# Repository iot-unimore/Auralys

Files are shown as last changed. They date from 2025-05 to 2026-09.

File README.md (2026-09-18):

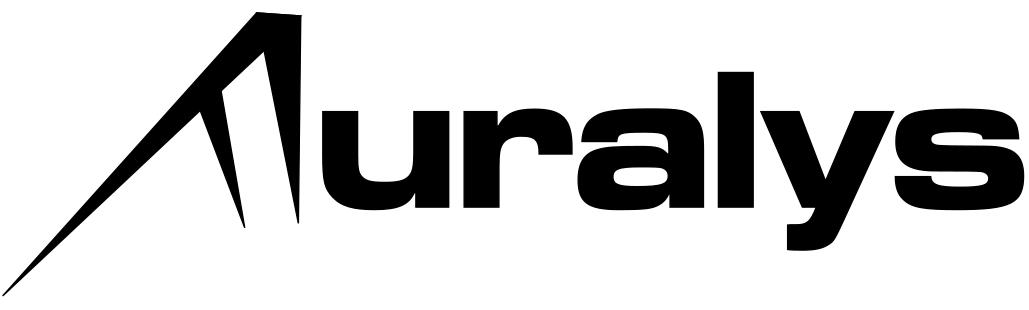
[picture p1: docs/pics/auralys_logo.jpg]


Auralys = Auris + Analysis

Auralys is an automated system for the measurement of head related transfer functions (HRTF) and room impulse
responses (RIR) of wearable devices carrying an array of microphones. It was built to characterise a pair of
glasses with six MEMS microphones, mounted on a 3D printed head, but the measurement system does not depend on
the device: any object with any number of microphones can be placed at the centre of the rig.

The whole system is designed to be rebuilt from this repository: 3D printed parts, off-the-shelf components,
electronics, firmware and software are all here, and no proprietary hardware or software is required.

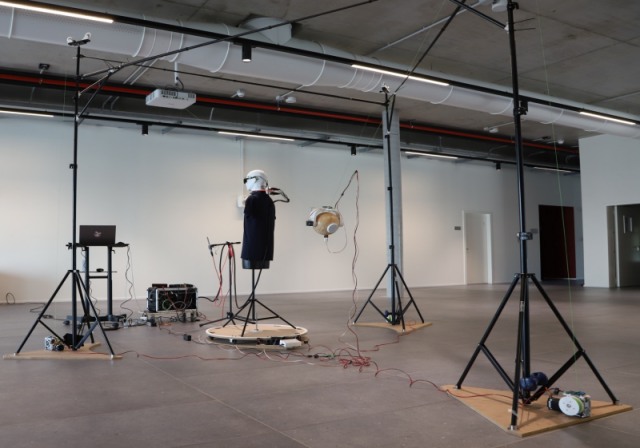
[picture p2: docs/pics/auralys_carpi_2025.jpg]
Auralys_carpi_2025


## What it does

A measurement campaign presents a loudspeaker at every direction of a grid around the device under test, plays an
exponential sine sweep at each direction, and records all the microphones together with a copy of the stimulus on
a single multichannel audio interface, so that all the tracks share one clock. The recordings are then processed
offline into impulse responses and assembled into AES69-2022 (SOFA) files.

The loudspeaker is moved in three dimensions by a cable suspension: three poles, each with a stepper motor winding
a thin rope, hold the speaker at any point of the working volume, and a small gimbal keeps it pointed at the
device. The device itself sits on a turntable that provides the azimuth rotation. Every motor is driven by the
same controller board and the same firmware (`firmware/auralysSpeaker`), configured for its role, and the host
talks to all of them over WiFi through a small REST API.

The work is split in two steps that never run together:

1. **Capture**, driven by `auralysCaptureHRTF.py`: positions the speaker, rotates the table, plays and records the
   sweep, and leaves on disk one folder per direction with the recording and a complete description of the setup
   (`config.yaml`).
2. **Processing**, done by the scripts under `hrtf/compute_hrir.py` and `hrft/compute_3dti_sofa.py`: deconvolution, time of arrival detection, and SOFA
   generation. This step reads only what the capture wrote and can be repeated at any time on any machine.

## Repository layout

| folder | content |
| --- | --- |
| `hardware/` | 3D models, schematics and gerber files: speaker, gimbal, turntable, poles and pulleys, motor controller, MEMS microphone board, power splitter, printed head (OpenAural) |
| `firmware/auralysSpeaker/` | Arduino sketch for the ESP32-S3 motor controller (pole, speaker gimbal, turntable), plus `cli/auralys_ctrl.py`, the command line tool that converts a position into rope lengths and drives the units |
| `hrtf/` | sweep recording (`record_ess_map.py`, `record_ess.py`), impulse response and SOFA computation (`compute_hrir.py`, `compute_3dti_sofa.py`, `compute_sofa.py`), tools; `ess_params.yaml` and `ess_map_params.yaml` describe the setup and the campaign |
| `audio/` | recording of ordinary audio material (not sweeps) over the same positioning loop |
| `docs/` | notes and coordinate tables |
| `auralysCaptureHRTF.py` | top level script for a full HRTF map (this file) |
| `auralysCaptureAudio.py` | top level script for an audio map with the same positioning loop |

Detailed documentation of the individual scripts will be added under `docs/`.

## Requirements

Hardware: the rig as described in `hardware/`, three pole units, one speaker unit and one turntable unit flashed
with the firmware and reachable on the local network, and one audio interface capable of simultaneous playback
and multichannel recording at 96 kHz, 24 bit (the scripts were developed with an RME Fireface UFX and a Focusrite
Scarlett 18i20).

Software: Linux with ALSA (`aplay` is used to find the interface), Python 3 with `numpy`, `pyyaml`, `sounddevice`,
`soundfile`, `requests`, `wget` and `multiprocess` for the capture step; the processing step additionally needs
`scipy`, `pyfar`, `sofar`, `matplotlib` and `setproctitle` (see `hrtf/readme.txt`).

## Running a capture with auralysCaptureHRTF.py

The script has no command line options: everything it needs is a constant at the top of the file, above the line
`DO NOT MODIFY CODE BELOW THIS LINE`. Before the first run:

1. Configure the positioning tool. The IP addresses of the five units, the geometry of the poles (heights and
   distances from the turntable) and the rope calibration constants are at the top of
   `firmware/auralysSpeaker/cli/auralys_ctrl.py`. Check them with a manual move:

   ```
   ./firmware/auralysSpeaker/cli/auralys_ctrl.py -c set position -p 1000,0,1650 -rs 0 -t ac -v
   ./firmware/auralysSpeaker/cli/auralys_ctrl.py -c cmd gozero -rs 0 -rt 0 -v
   ```

2. Describe the setup in `hrtf/ess_params.yaml`: the receivers (name, description, track index on the audio
   interface, position in the listener frame), the emitter (the speaker and the track of its loopback), the room,
   the author and the licence. This file is copied into every measurement as `config.yaml` and everything the
   processing knows about the setup comes from it.

3. Set the sweep parameters and the azimuth grid in `hrtf/ess_map_params.yaml`, or accept the defaults (20 Hz to
   20 kHz, 15 s, amplitude 0.8, 2 s of silence before and after, 96 kHz, 24 bit).

4. Edit the constants of `auralysCaptureHRTF.py`:
   - `_AUDIO_RECORDING_DEVICE_ID` / `_AUDIO_PLAYBACK_DEVICE_ID`: the name of the interface as printed by
     `aplay -l`; both must be the same interface;
   - `_AZIMUTH_BEGIN`, `_AZIMUTH_END`, `_AZIMUTH_STEP`: the azimuth range of every ring (default 360 down to 5 in
     steps of -5, that is 72 directions);
   - `auralysPositions`: one row per elevation ring, `[elevation, x, z]` in degrees and millimetres, with the
     speaker on a circle of 1 m radius around the head origin. Comment out the rows you do not need;
   - the output folder and the session name in the `record_ess_map.py` call (`-m` and `-n`).

Then, with the rig at its home position and the device under test on the table:

```
./auralysCaptureHRTF.py
```

For each ring the script moves the speaker, tilts it towards the head, waits for the ropes to settle, and starts
`hrtf/record_ess_map.py`, which rotates the table to every azimuth and records one sweep per direction. At the end
the speaker and the table are sent back to zero. An elevation the speaker could not reach, or a direction that
could not be recorded, is skipped and listed at the end, and the exit code is non-zero: a run that ends without
errors is complete.

The output is one folder per direction under the session folder:

```
<session>/
  <name>_+000+030+001_xAngle/      azimuth 0, elevation +30, distance 1 m
    config.yaml                    setup and stimulus actually used
    sweep_0.wav                    all interface inputs, 24 bit, 96 kHz
    sweep_99.wav                   preamble recording, not used
  <name>_+355+030+001_xAngle/
  ...
```

A dry run of the mechanics without audio is possible by adding `-t` to the `record_ess_map.py` call in the
script.

## Processing the recordings

The scripts under `hrtf/` turn a session folder into impulse responses and SOFA files; `hrtf/runme_all.sh` runs
the complete sequence on one session and `hrtf/usage_notes.txt` shows the individual commands. The resulting SOFA
files are the input of the [VERSE](https://github.com/iot-unimore/verse) framework.

## Note on the output location: `-m` and `-n`

The two values that change at every campaign are the output folder and the session name, the `-m` and `-n`
options of `hrtf/record_ess_map.py`. They are passed by `auralysCaptureHRTF.py` in its call to
`record_ess_map.py` and are the first thing to edit before a run:

```
"-m", "/media/gfilippi/audiodata/auralysNoHead_20260905-001",   # output folder of the session
"-n", "auralysNoHead",                                          # session name, prefix of every direction folder
```

`-m` is the session folder, created if it does not exist; a full map is several gigabytes of 24 bit
multichannel audio, so point it to a drive with room. Its last path component becomes the prefix of the SOFA
files produced later (`auralysNoHead_20260905-001_binaural.sofa` and so on). `-n` is the prefix of the folder of
every direction (`<name>_+AAA+EEE+DDD_xAngle`) and of the `config.yaml` entries that name it.
Running twice with the same `-m` and `-n` overwrites the recordings of the directions in common, so use a new
session folder for every campaign.

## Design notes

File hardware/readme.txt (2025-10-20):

this folders contains the list of parts to rebuild the speaker, rotating table, suspension poles.

the motor controller is universal (one pcb for all roles, spearker or suspension pole)

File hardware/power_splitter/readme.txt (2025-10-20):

a simple pcb to split the 24v between all the motor controls and rotating table of verse.

diode is present to prevent polarity inversion.

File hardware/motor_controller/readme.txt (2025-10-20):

the motor controller will run the auralysSpeaker firmware and it is the same for ALL the motors in the system.

different settings for speed (and role) allows the software to change the behavior, but the firmware is the same on all devices.

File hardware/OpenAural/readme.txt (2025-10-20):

https://www.thingiverse.com/thing:4691843

https://www.sciencedirect.com/science/article/pii/S0003682X20307143

===

Using both ears the human brain processes both monaural and inter-aural cues resulting from the scattering of sound by the head and torso in order to localise the source of a sound.  A common method to replicate these cues for playback has been to build a human dummy head and torso simulator (HATS) and place microphones at each ear canal to replicate the effect the human anatomy has on the sound field.

A binaural device was successfully designed for manufacture on a range of 3D printers. Full details of the design and experimental validation can be found here:

O’Connor D, Kennedy J. An evaluation of 3D printing for the manufacture of a binaural recording device. Applied Acoustics. 2021 Jan 1;171:107610. 

https://doi.org/10.1016/j.apacoust.2020.107610

The excellent agreement between the developed system and the BEM simulations demonstrates the validity of the system for many acoustic problems. At present the developed system is being used for subjective listening tests in the context of environmental noise annoyance.

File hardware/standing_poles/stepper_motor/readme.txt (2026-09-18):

motor is a MKS SERVO57D (485)

https://makerbase3d.com/product/makerbase-mks-servo57d/

gearbox for rpm reduction

https://it.aliexpress.com/item/1005002212151972.html

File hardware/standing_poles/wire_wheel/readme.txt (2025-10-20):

each wire is suspended over two wheels.

each wheel is made of two parts (identical) glue toghether and attached to the support using two ball bearings.

each plate mounted on top of the pole has two supports for two wheels

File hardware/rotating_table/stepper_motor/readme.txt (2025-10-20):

https://makerbase3d.com/product/makerbase-mks-servo57d/

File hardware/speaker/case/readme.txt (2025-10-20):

the speaker case is made of two bambu bowls glued toghether.

it is a cheap solution to get a rounded shape speaker that can rotate on the horizontal axis

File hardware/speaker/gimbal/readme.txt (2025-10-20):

the gimbal support for the speaker is printed in multiple parts.

- one plate
- two sides
- two curves

that need to be assembled using 4mm and 5mm nuts and bolts

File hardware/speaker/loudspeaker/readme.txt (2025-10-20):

FAITAL-PRO

4FE43 - 8ohm

https://faitalpro.com/en/products/LF_Loudspeakers/product_details/index.php?id=401005100

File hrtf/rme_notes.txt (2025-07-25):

IMPORTANT: 
==========
If you are using an RME (www.rme-audio.de) audio card with linux,
you need to add the following define to ~/.bashrc :

PA_ALSA_PLUGHW=1
export PA_ALSA_PLUGHW

note: make sure to log-out, log-in after adding the above.

FFPLAY specific device playback:
================================
SDL_AUDIODRIVER="alsa" AUDIODEV="hw:2,0" ffplay ./pinknoise_0.8A_30s.wav

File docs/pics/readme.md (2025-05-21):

===

Auralys is the combination of AURIS (meaning ear in latin language) and ANALYSIS

===

The first letter "A" of the Auralys logo is the rune symbol for A, referring to ANSUZ.

The Ansuz rune is associated with divine communication, wisdom, inspiration, and the power of words. 
It signifies the arrival of profound messages and the ability to articulate them clearly, 
whether through spoken words, written texts, or intuitive understanding. 
It also represents the connection between the divine and human, and the reception and application 
of spiritual knowledge. 

Ansuz is often seen as the rune of divine messages and the ability to receive and transmit spiritual knowledge. 

-EOF-

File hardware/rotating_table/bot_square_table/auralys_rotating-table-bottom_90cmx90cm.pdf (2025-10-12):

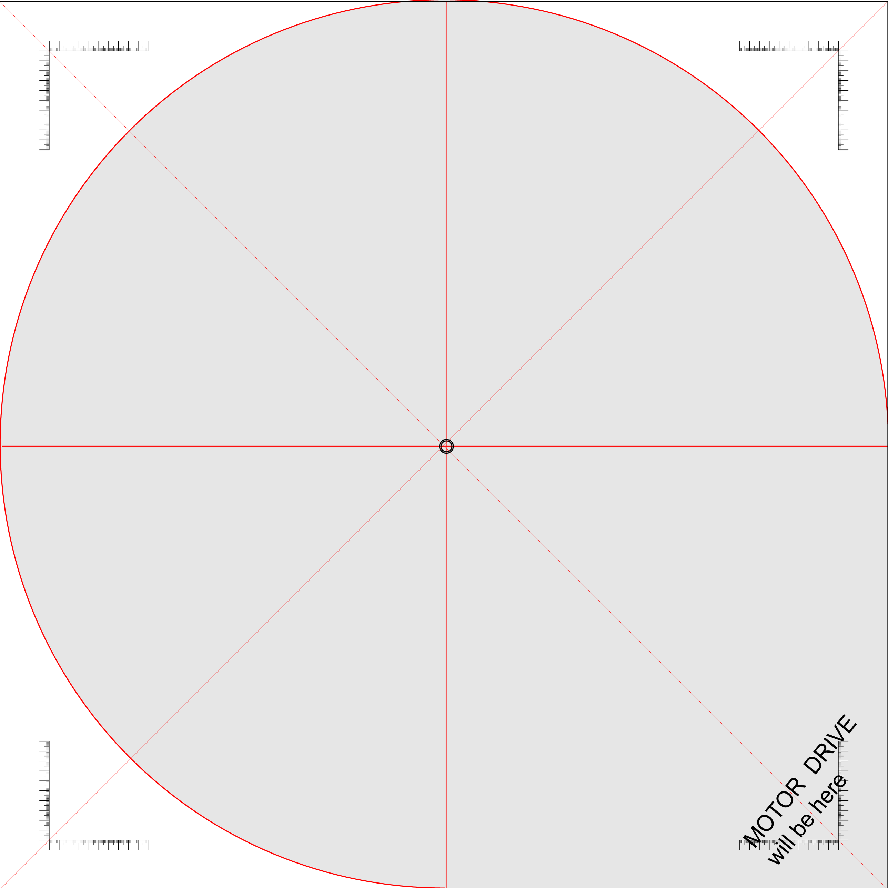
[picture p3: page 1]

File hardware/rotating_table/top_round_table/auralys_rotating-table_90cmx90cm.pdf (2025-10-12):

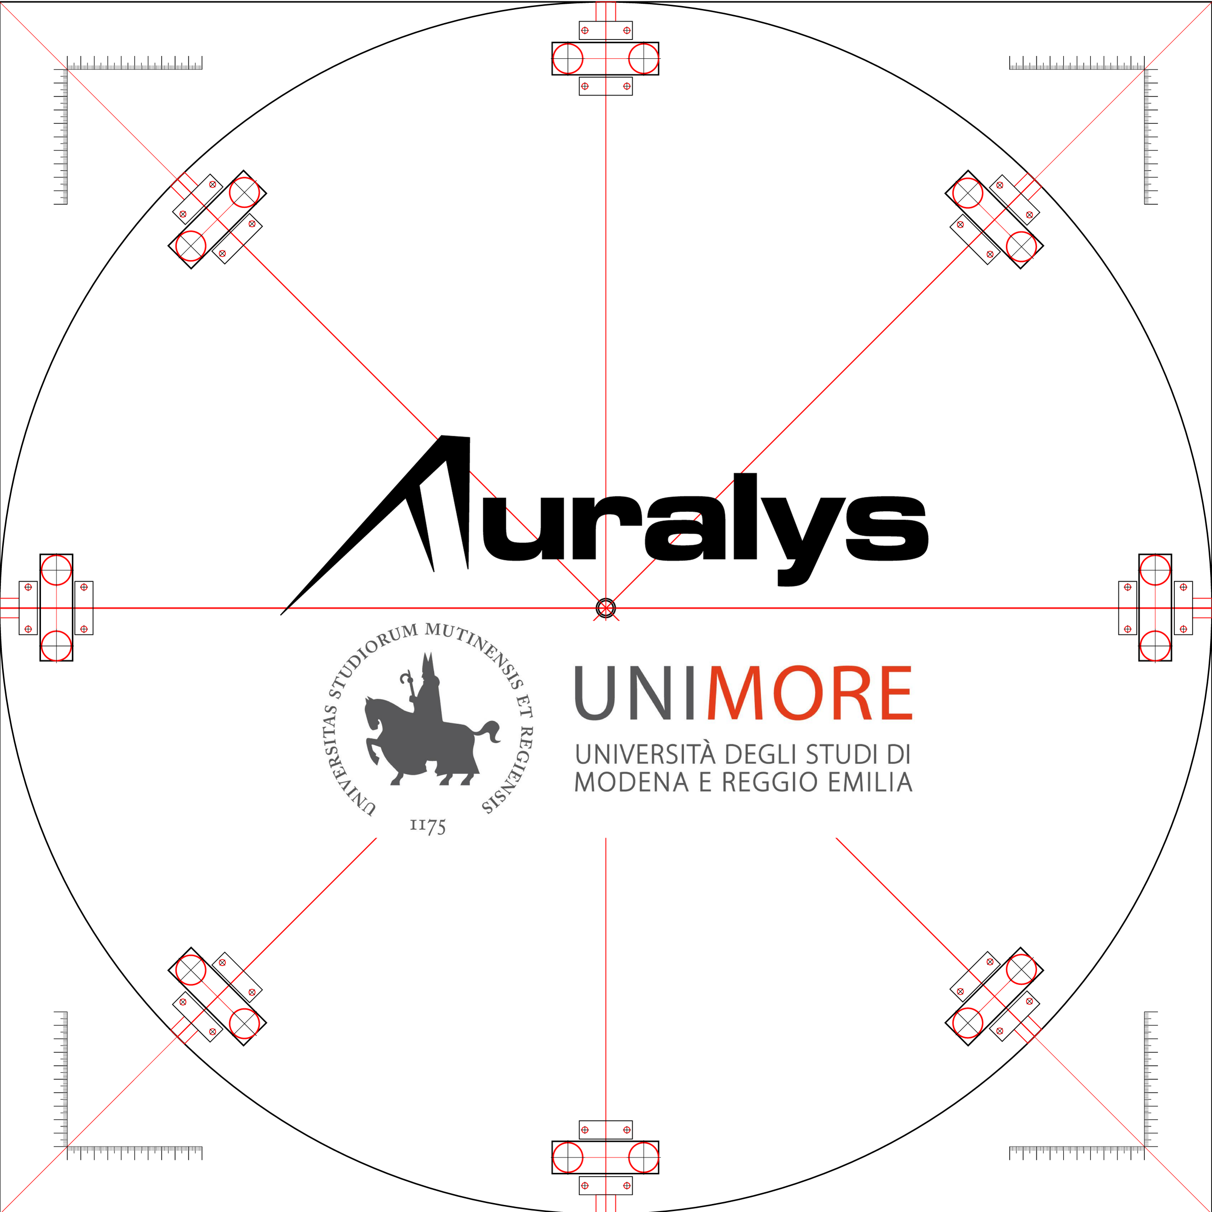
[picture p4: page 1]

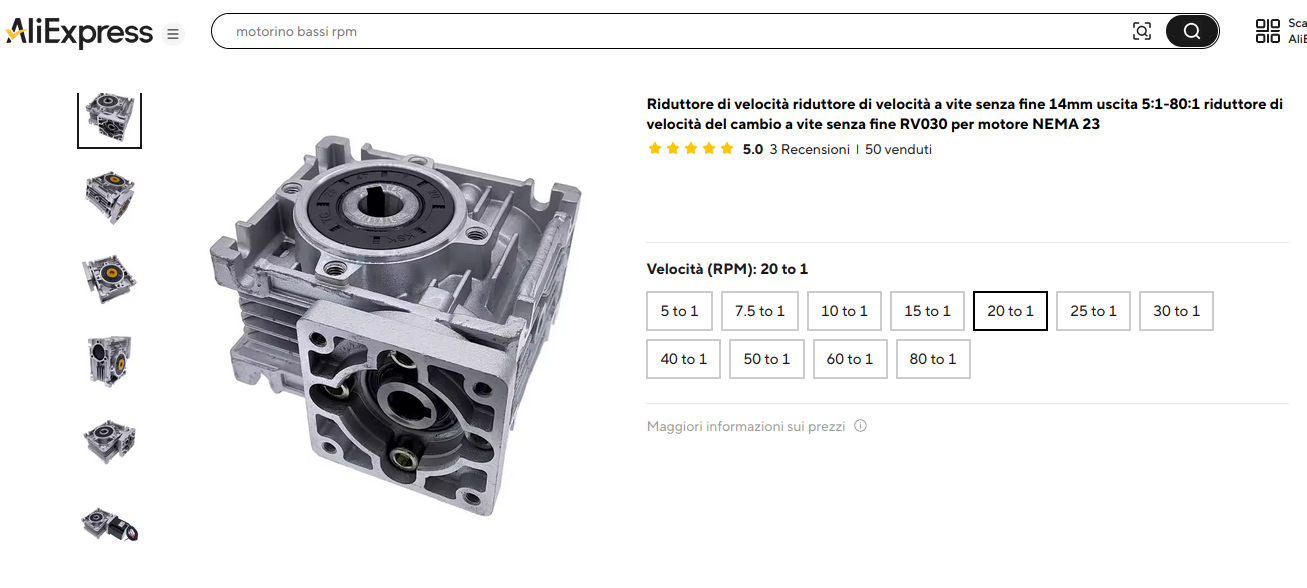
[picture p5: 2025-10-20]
hardware/standing_poles/stepper_motor/gearbox.png

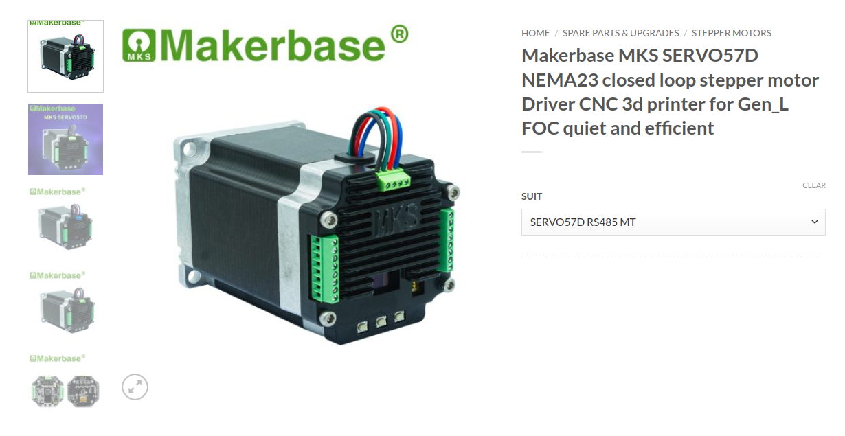
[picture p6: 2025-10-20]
hardware/rotating_table/stepper_motor/mks_servo57D_485.png

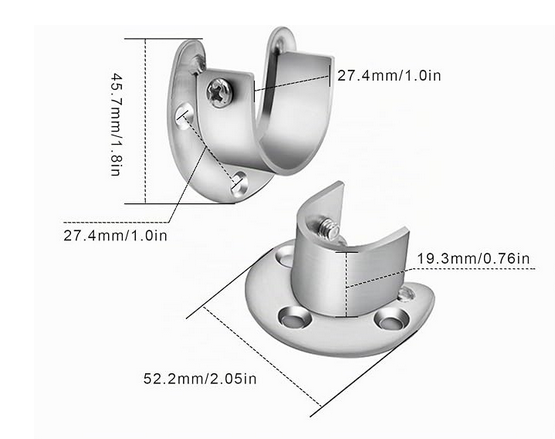
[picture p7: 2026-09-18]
hardware/standing_poles/feed_asapters.png

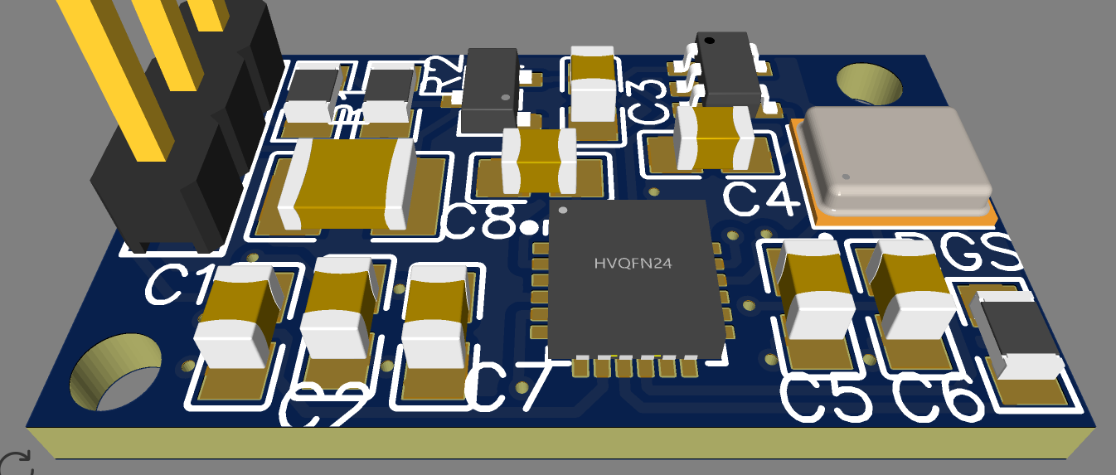
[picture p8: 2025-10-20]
hardware/glasses/mems_mic/mems_mic.png

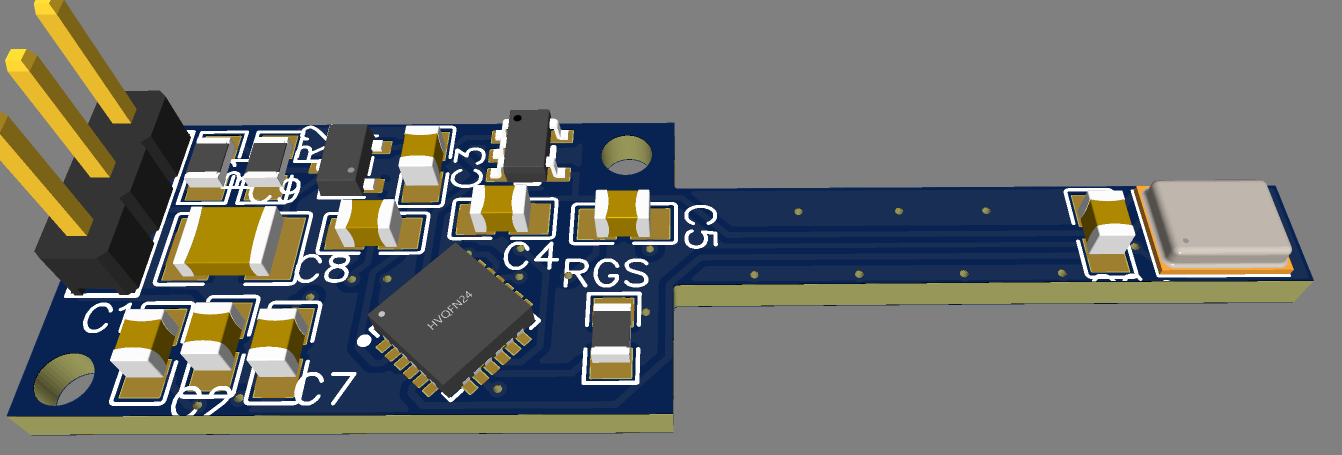
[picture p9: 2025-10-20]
hardware/glasses/mems_mic/mems_mic_long.png

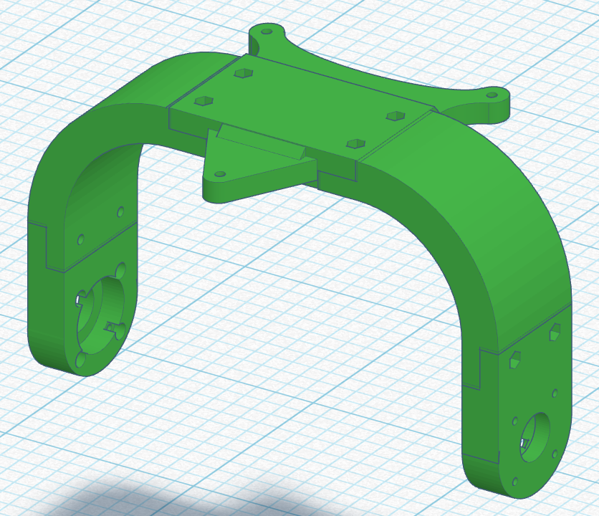
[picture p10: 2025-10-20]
hardware/speaker/gimbal/auralys_speaker_gimbal_01.png

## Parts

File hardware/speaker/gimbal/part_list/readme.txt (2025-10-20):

the gimbal stepper motor is controlled by a MAKERBASE MKS 42S (RS485) controller

https://makerbase.com.cn/en/

https://makerbase3d.com/product-category/brands/mks/servo/

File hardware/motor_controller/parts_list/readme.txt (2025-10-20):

MAIN CPU:
https://www.wemos.cc/en/latest/s3/s3_mini.html

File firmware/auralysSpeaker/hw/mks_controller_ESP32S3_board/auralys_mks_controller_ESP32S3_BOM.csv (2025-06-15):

ID | Name | Designator | Footprint | Quantity | Manufacturer Part | Manufacturer | Supplier | Supplier Part | Price
1 | HDR-F-2.54_1x3 | H4 | HDR-F-2.54_1X3 | 1 |  |  | LCSC | C146690 | 0.086
2 | AO3400A_C347475 | Q1 | SOT-23-3_L2.9-W1.3-P1.90-LS2.4-BR | 1 | AO3400A | UMW(友台半导体) | LCSC | C347475 | 0.031
3 | WEMOS-S3-MINI | U1 | WEMOS-S3-MINI | 1 | Wemos | WEMOS | WEMOS | WEMOS_S3_MINI
4 | 10kΩ | R1,R2,R3,R4,R5 | R0805 | 5 | 0805W8F1002T5E | UNI-ROYAL(厚声) | LCSC | C17414 | 0.002
5 | HDR-F-2.54_1x2 | H1,H3 | HDR-F-2.54_1X2 | 2 |  |  | LCSC | C49661 | 0.038
6 | ADJ-STEP-DOWN | U4 | ADJ-STEP-DW | 1
7 | SERIAL-to-485 | U5 | SERIAL-TO-485 | 1
8 | PWR_YE0192 | U6 | PWR_YE1092 | 1
9 | JST-XH-04-PIN-LONG-PAD | X1 | JST-XH-04-PACKAGE-LONG-PAD | 1
10 | K2-3.6×6.1_SMD | KEY1,KEY2,KEY3 | KEY-SMD_2P-L6.2-W3.6-LS8.0 | 3 | K2-1107ST-A4SW-06 |  | LCSC | C118141 | 0.062
11 | WCMCU-LIS3DH | U2 | WCMCU_LIS3DH | 1
12 | GME12864 | U3 | OLED-GME12864 | 1 | 1.3寸OLED显示屏12864 | null |  | C9900014198

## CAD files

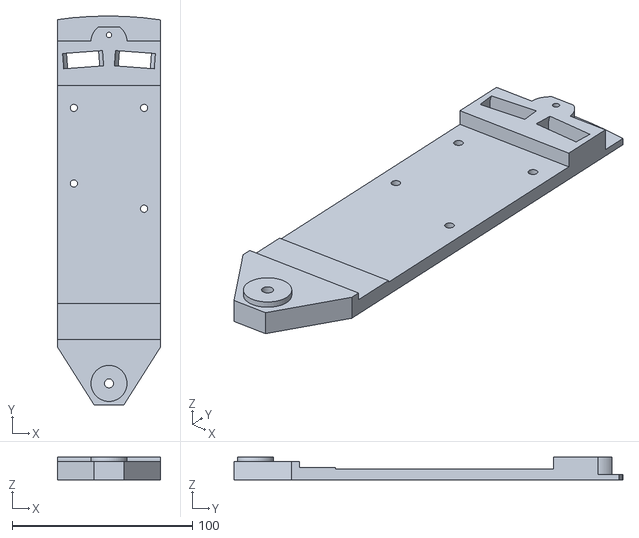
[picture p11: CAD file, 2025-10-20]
hardware/rotating_table/stepper_motor/motor_support/MKS_RTable_FULL.stl
57.0 x 216.0 x 12.5

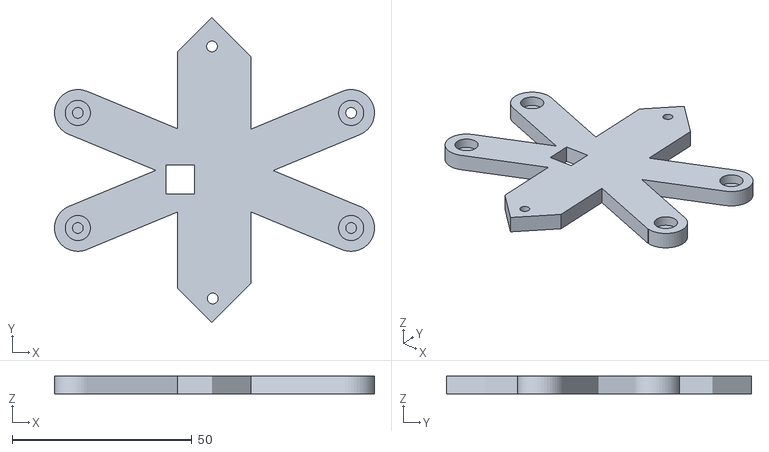
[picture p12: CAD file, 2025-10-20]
hardware/motor_controller/MKS_ctrl_star_mount.stl
89.0 x 84.9 x 5.00

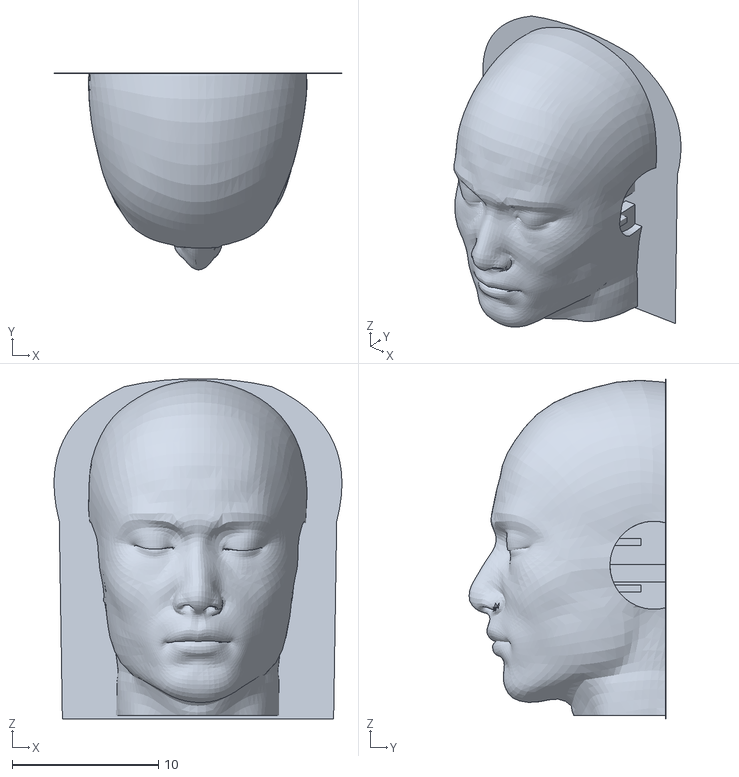
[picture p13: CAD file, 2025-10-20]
hardware/OpenAural/Head_front.STL
19.7 x 13.5 x 23.3

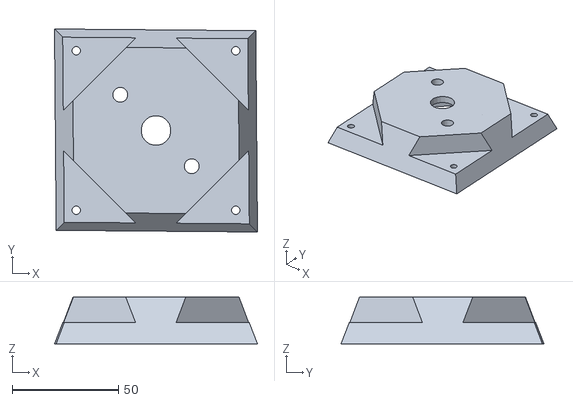
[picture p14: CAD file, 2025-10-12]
hardware/rotating_table/bot_square_table/parts_list/center_shaft_bearing_support.stl
95.5 x 95.5 x 22.0

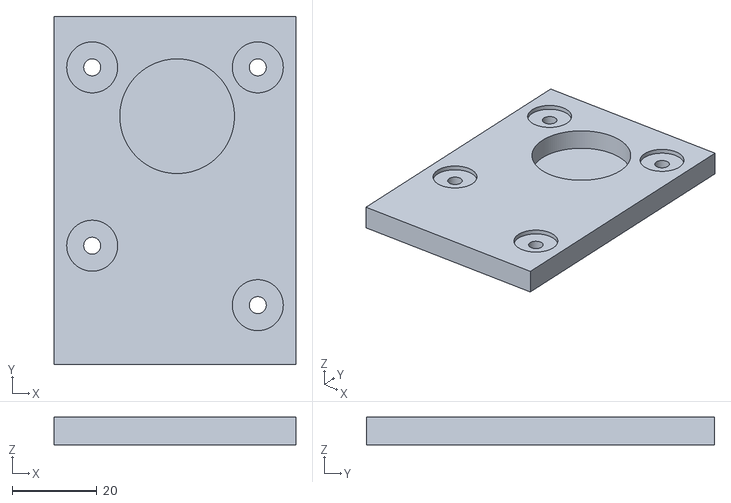
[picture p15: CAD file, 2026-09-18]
hardware/rotating_table/stepper_motor/motor_support/MKS_RTable_gearbox_plate.stl
57.0 x 82.0 x 6.50

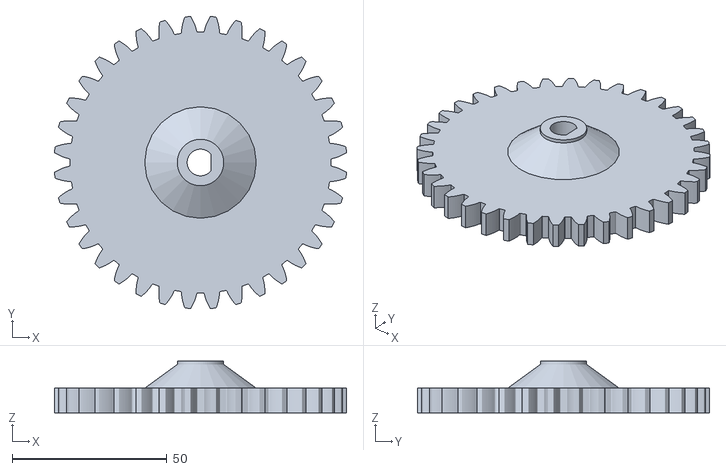
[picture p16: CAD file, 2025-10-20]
hardware/rotating_table/stepper_motor/spurgear-III_small.stl
94.3 x 94.3 x 16.8

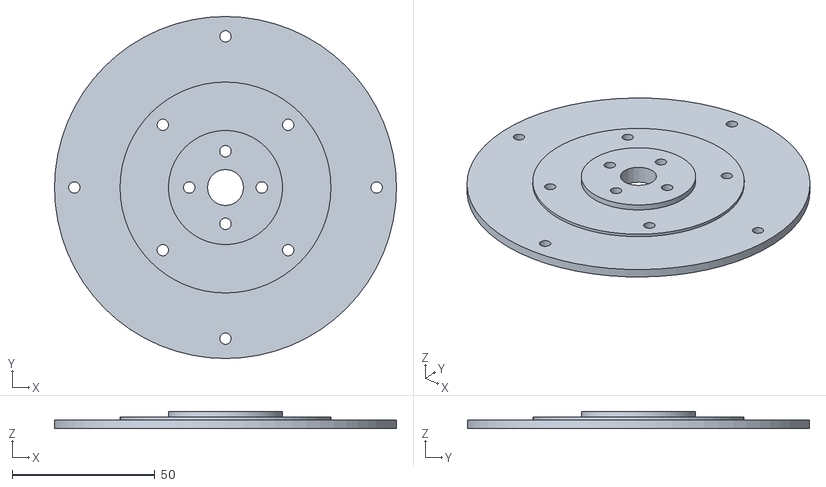
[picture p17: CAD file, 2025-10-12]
hardware/rotating_table/top_round_table/parts_list/center_shaft_flange_extension.stl
120.0 x 120.0 x 6.00

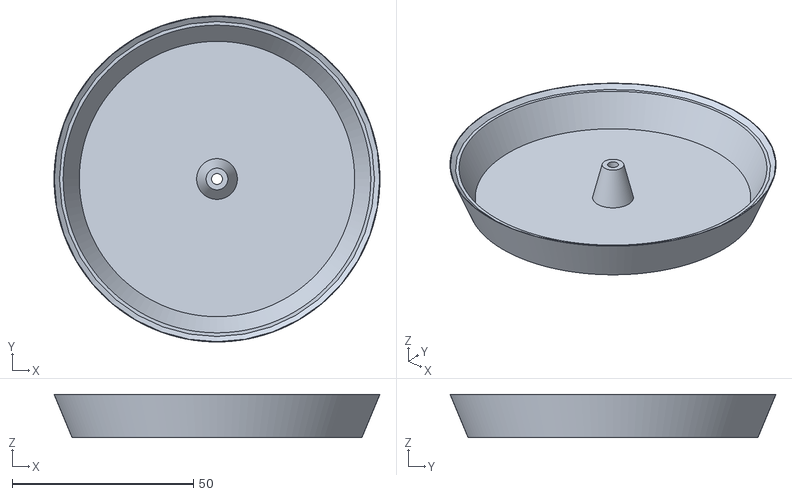
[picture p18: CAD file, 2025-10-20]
hardware/speaker/case/speaker_counterweight.stl
90.0 x 90.0 x 12.0

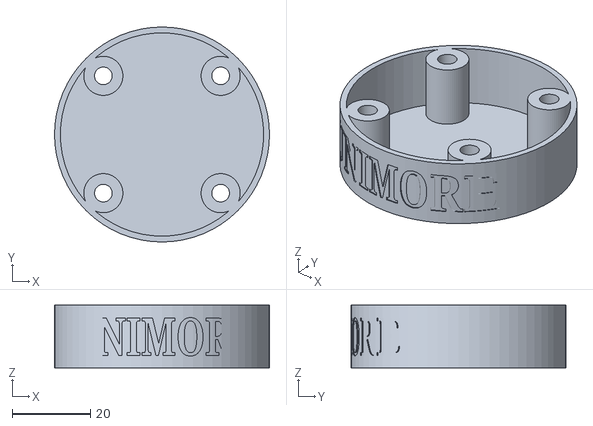
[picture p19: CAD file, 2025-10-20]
hardware/speaker/gimbal/gimba_cover.stl
55.0 x 55.0 x 16.0

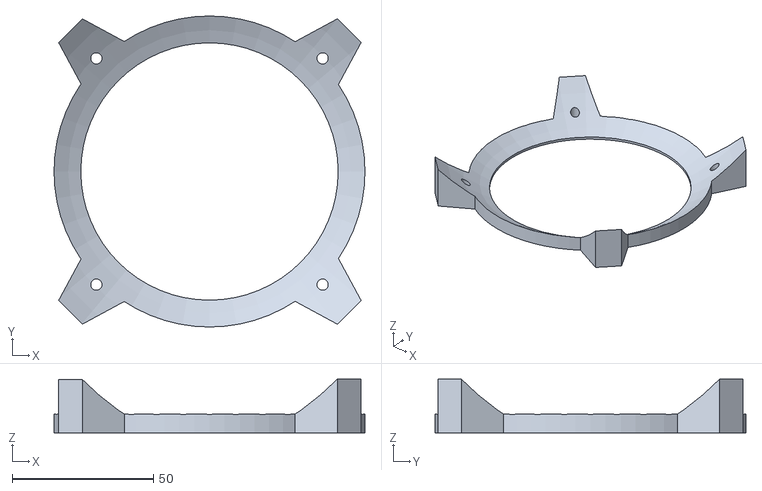
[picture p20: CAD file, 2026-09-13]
hardware/speaker/loudspeaker/Faital-4FE32.stl
110.0 x 110.0 x 19.0

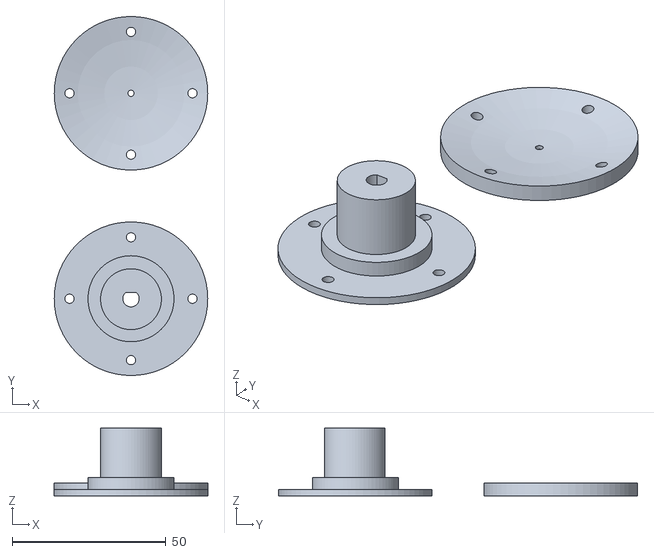
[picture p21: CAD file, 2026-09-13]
hardware/speaker/stepper_motor/mks_wilpkr_flange_v2.stl
50.0 x 116.9 x 22.0

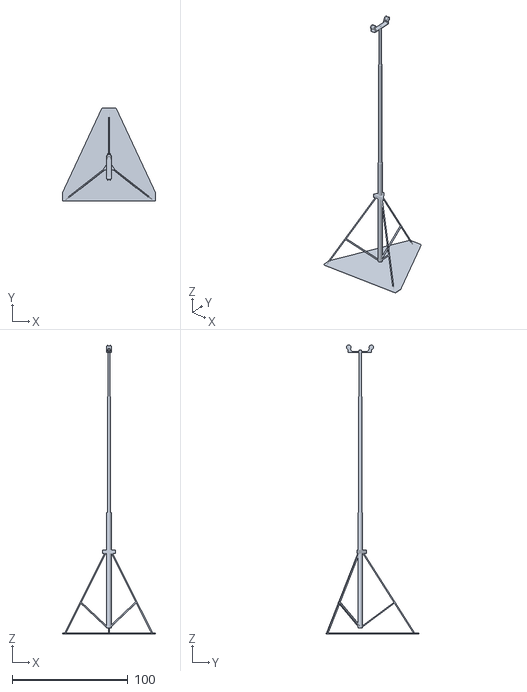
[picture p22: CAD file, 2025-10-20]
hardware/standing_poles/auralys_standing_pole.stl
80.0 x 80.0 x 249.5

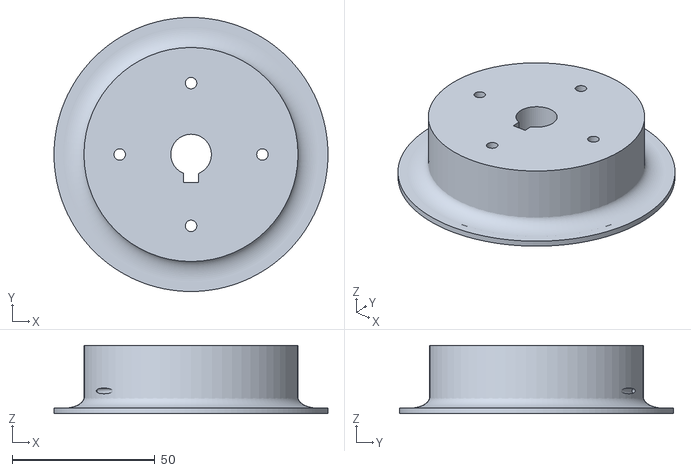
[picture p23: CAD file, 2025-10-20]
hardware/standing_poles/stepper_motor/mks_9cm-II_spool.stl
96.0 x 96.0 x 24.0

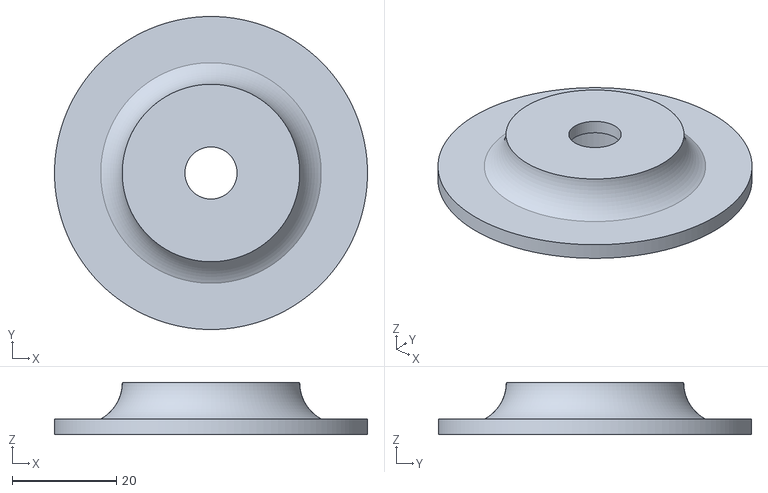
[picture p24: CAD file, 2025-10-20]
hardware/standing_poles/wire_wheel/mks_wire_2wheel.stl
60.0 x 60.0 x 10.00

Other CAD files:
hardware/OpenAural/Ear_right.stl
hardware/rotating_table/stepper_motor/motor_support/MKS_RTable_base.stl
hardware/rotating_table/top_round_table/parts_list/spurgear_90cm_element_x4.stl
hardware/speaker/gimbal/gimbal_plate.stl
hardware/OpenAural/Ear_left.STL
hardware/OpenAural/Head_back.STL
hardware/OpenAural/head_front_V_Bolt_withoutbrim.STL
hardware/rotating_table/stepper_motor/motor_support/MKS_RTable_perno.stl
hardware/rotating_table/stepper_motor/motor_support/MKS_RTable_wheels-3.stl
hardware/rotating_table/stepper_motor/motor_support/MKS_holder.stl
hardware/rotating_table/stepper_motor/motor_support/MKS_support_plate.stl
hardware/speaker/gimbal/gimbal_curve.stl
hardware/speaker/gimbal/gimbal_side.stl
hardware/standing_poles/stepper_motor/mks_9cm_spool.stl
hardware/standing_poles/wire_wheel/mks_wire_holder_wheel.stl

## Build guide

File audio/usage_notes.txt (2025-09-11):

# example to run muxer on audio recording folder

./muxAudioMKV.py -r -v -c 16 -d 0.0008 -i /media/gfilippi/bigdata_01/auralys_measures/test

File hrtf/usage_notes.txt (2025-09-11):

#
# playback of audio file
#
./play_file.py -o hw:2,0 ../pink_noise_30s.wav

#
# example for single sweep recording from command line
#
./record_ess.py -o hw:2,0 -i hw:3,0 -b 20 -e 20000 -a 0.8 -d 10 -r 3 -m ./measures/ -v

#
# examples for full map (multiple sweeps) recording from command line
#
./record_ess_map.py -o hw:2,0 -i hw:3,0 -b 20 -e 20000 -aa 0.8 -d 1 -r 1 -m ./measures/test20240801/ -n test -ab 3 -ae 50 -as 2 -yp ./ess_map_params.yaml -yc ./ess_params.yaml
./record_ess_map.py -o hw:2,0 -i hw:3,0 -b 20 -e 20000 -a 0.8 -d 1 -r 1 -m ./measures/test20240801/ -n test -z 3 -x 50 -c 2
./record_ess_map.py -v -yp ./ess_map_params.yaml -ab 0 -ae 2 -m ./measures/test-20240901 -n test

# compute impulse responses on ALL the sweeps recorded under a measure folder
./compute_hrir.py -mf ./measures/test-20240816_001/ -v

#=============================================================================================
# JAN 2025: full pipeline procedure
#=============================================================================================

# STEP-1
# record full map with azimuth 5deg incremental step
./record_ess_map.py -v -yp ./ess_map_params.yaml -ab 0 -ae 358 -as 15 -m ./measures/dry-20250123_002 -n dry

# STEP-2
# compute impulse responses on ALL recordings in a measure session, DSP_delay is 0.9ms
./compute_hrir.py -v -c 44 -d 0.0009 -mf ./measures/dry-20250123_002

# STEP-3 (optional)
# compute AES69-2022 sofa file for impulse responses
# this will produce file: ./measures/dry-20250123_002//dry-20250123_002.sofa
./compute_sofa.py -v -c 88 -mf ./measures/dry-20250123_002/
# visualize any of the above sofa maps, ALL impulse responses
./display_sofa.py -v -mf ./measures/dry-20250123_002//dry-20250123_002.sofa
# visualize any of the above sofa maps, select source position and receiver track
./display_sofa.py -v -mf ./measures/dry-20250123_002//dry-20250123_002.sofa -sss 270,45,1 -ssr 4

# STEP-4
# split sofa in multiple "FreeField" binaural impulse responses, one sofa file for each
# configuration of the wilso_prj microphones (binaura, array_six|front|middle|read)

# 3DTuneIn requires IR to be aligned on the direct_path peak to allow HRTF interpolation.
# The "zero-delay" option will write the IR delays in DataDelay of the SOFA file,
# removing the time delay from the IR array.We use a small ir window to cut reverberations
# IR Peak Delays are also kept in sofa user variable IRPeakDelay
./compute_3dti_sofa.py -v -c 88 -mf ./measures/dry-20250123_002/ -irw 0.015 -z -s binaural
./compute_3dti_sofa.py -v -c 88 -mf ./measures/dry-20250123_002/ -irw 0.015 -z -s array_six,front
./compute_3dti_sofa.py -v -c 88 -mf ./measures/dry-20250123_002/ -irw 0.015 -z -s array_six,middle
./compute_3dti_sofa.py -v -c 88 -mf ./measures/dry-20250123_002/ -irw 0.015 -z -s array_six,rear

# Non zero-delay: use this only if you want to keep the delay as part of the IR response.
# note: this is not optimal for 3DTuneIn since it will cause comb filtering effect when the
# HRTF interpolation is enabled (check if you disabled the option). 
# We use a small ir window to cut reverberations.
# IR Peak Delays are also kept in sofa user variable IRPeakDelay
./compute_3dti_sofa.py -v -c 88 -mf ./measures/dry-20250123_002/ -irw 0.015 -s binaural
./compute_3dti_sofa.py -v -c 88 -mf ./measures/dry-20250123_002/ -irw 0.015 -s array_six,front
./compute_3dti_sofa.py -v -c 88 -mf ./measures/dry-20250123_002/ -irw 0.015 -s array_six,middle
./compute_3dti_sofa.py -v -c 88 -mf ./measures/dry-20250123_002/ -irw 0.015 -s array_six,rear

# these 3dti sofa files will be generated
# ./measures/dry-20250123_002/dry-20250123_002_binaural.sofa
# ./measures/dry-20250123_002/dry-20250123_002_array_six_front.sofa
# ./measures/dry-20250123_002/dry-20250123_002_array_six_middle.sofa
# ./measures/dry-20250123_002/dry-20250123_002_array_six_rear.sofa

# visualize any of the above sofa maps, select source position
./display_sofa.py -v -mf ./measures/dry-20250123_002//dry-20250123_002_binaural.sofa -sss 270,45,1

# STEP-5
# from mono audio source(s) recreate the full auralization over a set of positions
# case 01: example for single source with fixed position (60deg left), without room reverberation
./render_3dti_audio.py -v -sf ./resources/voices/voice_001.wav -hf ./resources/heads/head_002/head_002.yaml -o ./dataset/pippo/ -sc 60,0,1
# case 02: example for single source with fixed position (60deg left), with reverberation
./render_3dti_audio.py -sf ./resources/voices/voice_001.wav -hf ./resources/heads/head_002/head_002.yaml -o ./dataset/pippo/ -ef ./resources/rooms/room_brir_001.yaml -sc 60,0,1 -v

# STEP-6
# merge auralized files into one multi-track file
ffmpeg -i front_left.wav -i front_right.wav -i front_center.wav -i lfe.wav -i back_left.wav -i back_right.wav \
-filter_complex "[0:a][1:a][2:a][3:a][4:a][5:a]amerge=inputs=6[a]" -map "[a]" output.wav

/usr/bin/ffmpeg -hide_banner -loglevel error -i ./resources/voices/voice_001.wav -i ./dataset/pippo/voice_001_binaural.wav \
-i ./dataset/pippo/voice_001_array_six_front.wav -i ./dataset/pippo/voice_001_array_six_middle.wav -i ./dataset/pippo/voice_001_array_six_rear.wav \
 -filter_complex "[0:a][1:a][2:a][3:a][4:a]amerge=inputs=5[a]" -map "[a]" ./dataset/pippo/voice_001_map.wav

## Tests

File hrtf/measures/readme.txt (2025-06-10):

folder to store measurements with the Auralys setup

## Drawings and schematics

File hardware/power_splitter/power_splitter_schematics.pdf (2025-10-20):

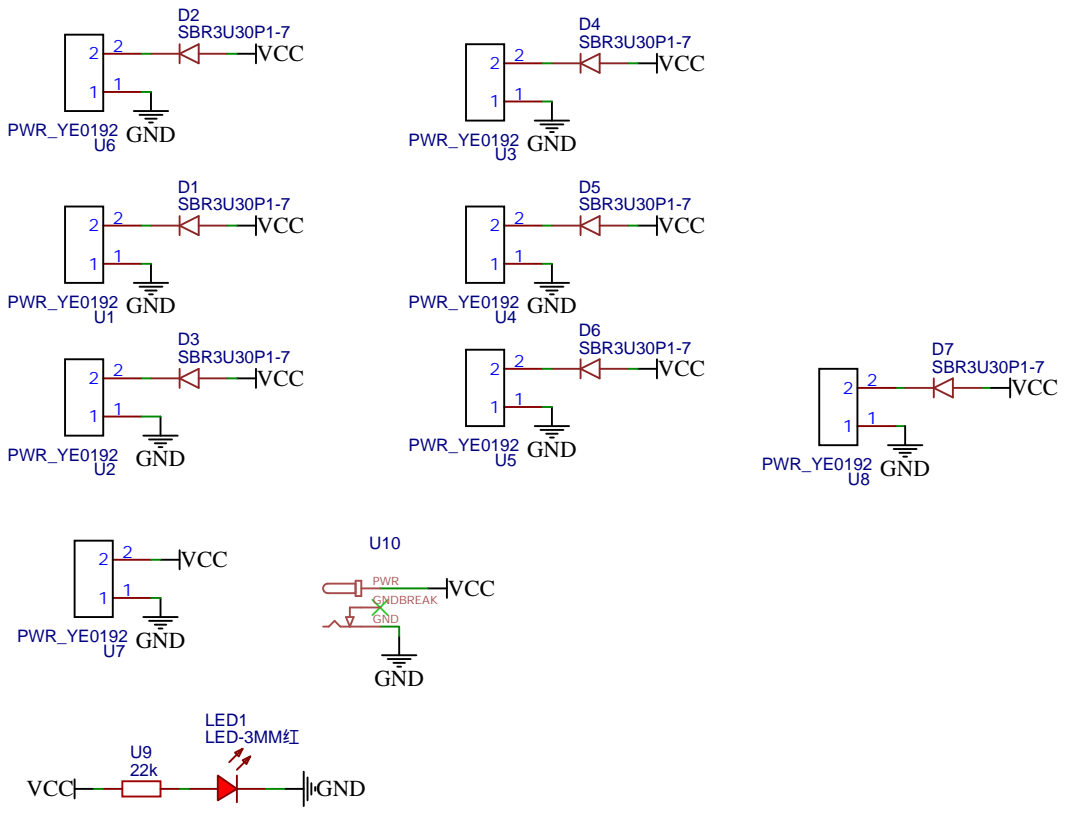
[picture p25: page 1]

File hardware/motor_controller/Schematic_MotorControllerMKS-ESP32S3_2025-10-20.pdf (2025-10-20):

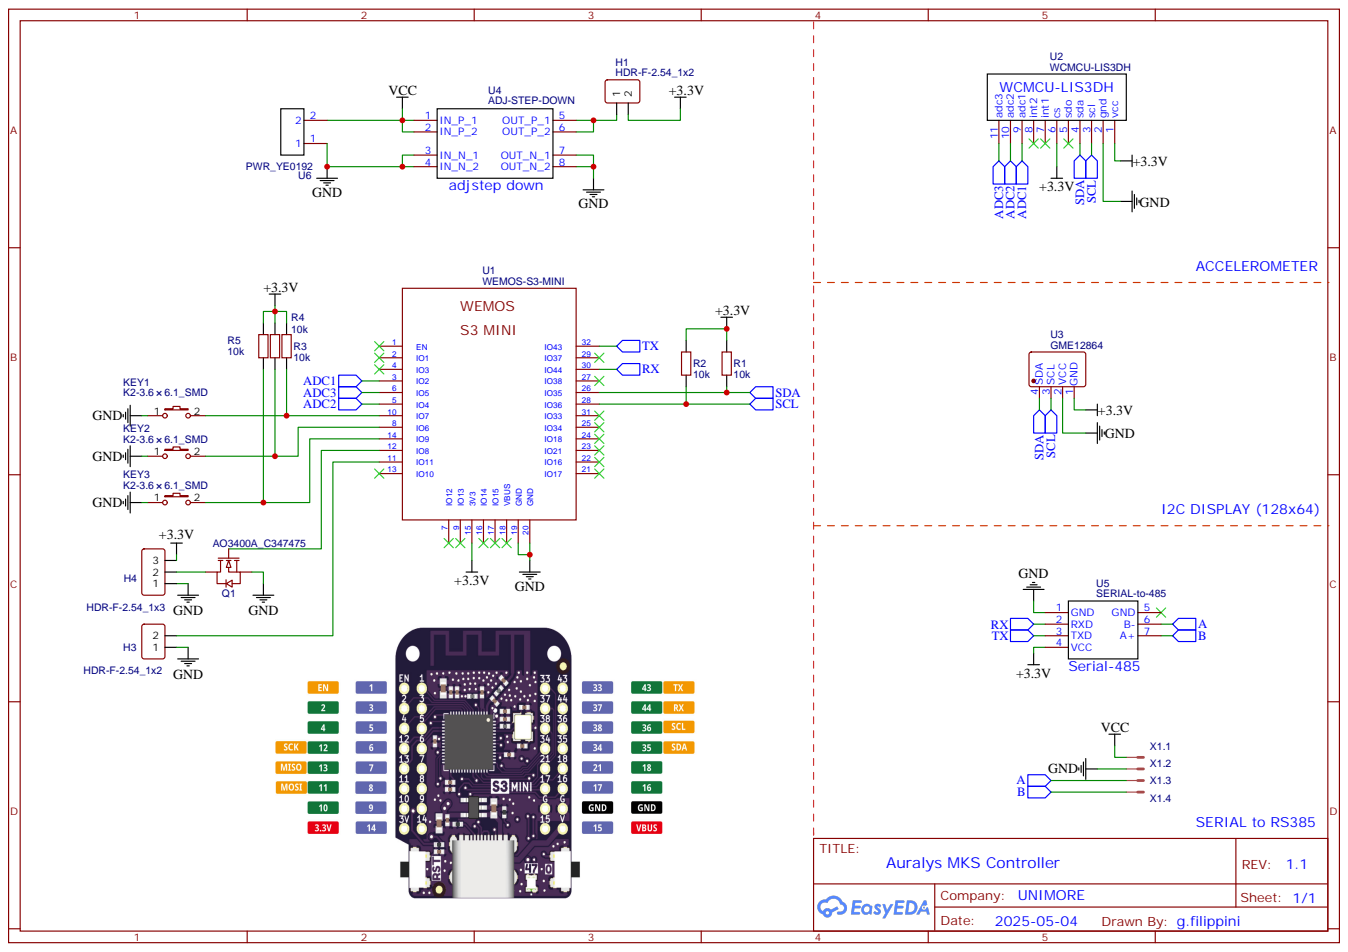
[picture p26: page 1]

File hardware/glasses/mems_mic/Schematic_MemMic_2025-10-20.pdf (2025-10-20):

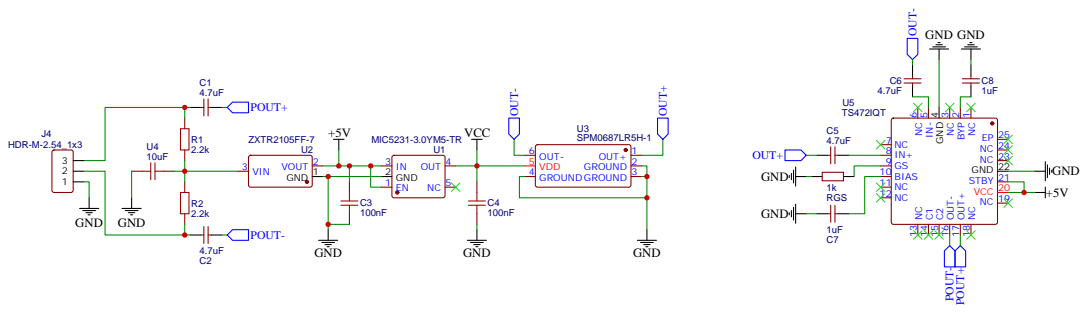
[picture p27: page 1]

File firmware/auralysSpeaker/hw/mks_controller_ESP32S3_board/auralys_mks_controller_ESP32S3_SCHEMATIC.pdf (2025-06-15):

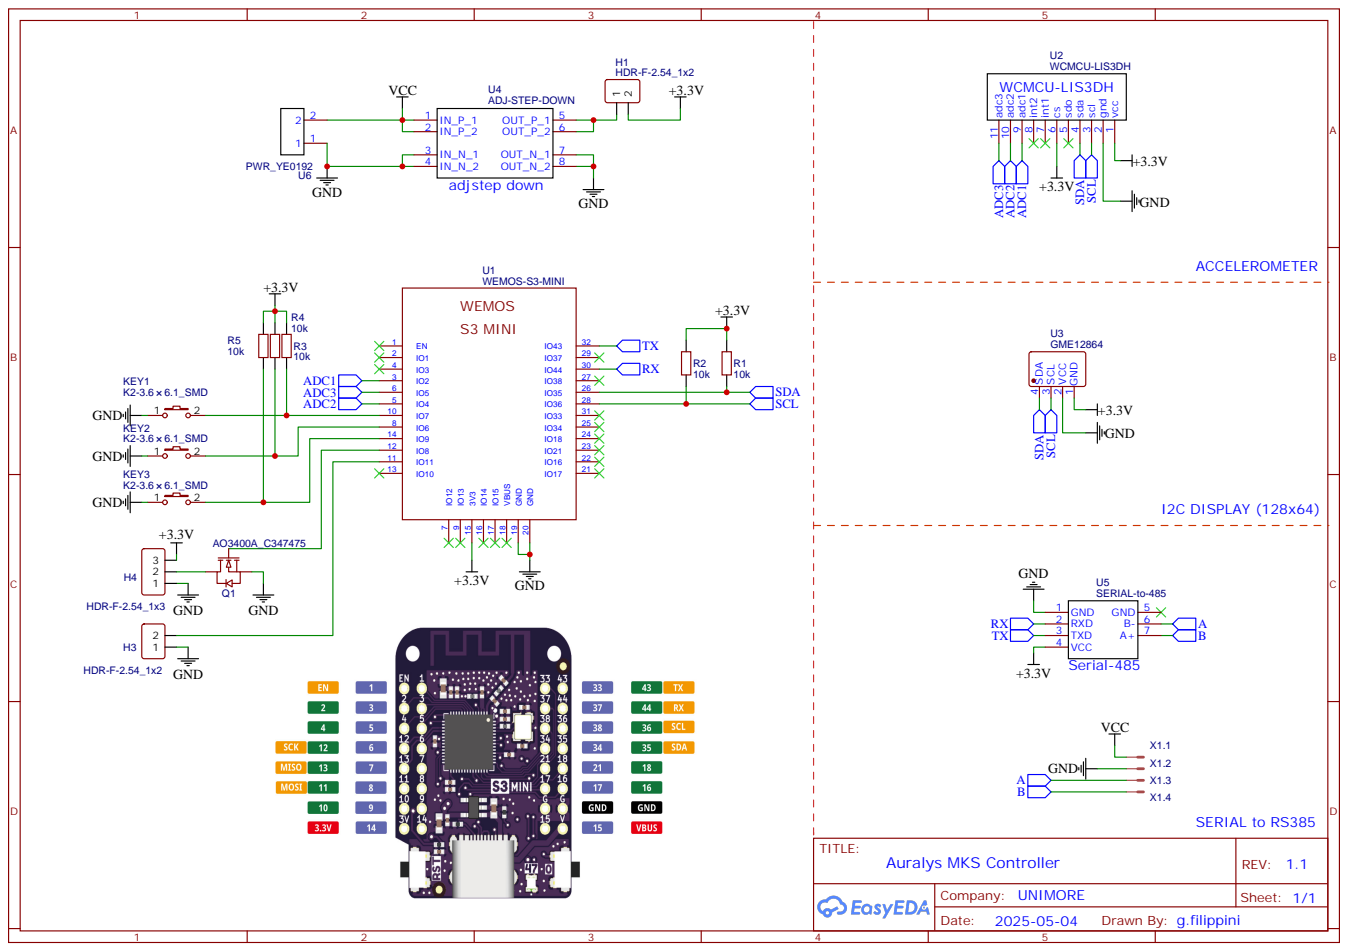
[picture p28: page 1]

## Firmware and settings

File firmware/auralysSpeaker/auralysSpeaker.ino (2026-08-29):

/*
 *    _  _   _ ___    _   _ __   _____
 *   /_\| | | | _ \  /_\ | |\ \ / / __|
 *  / _ \ |_| |   / / _ \| |_\ V /\__ \
 * /_/ \_\___/|_|_\/_/ \_\____|_| |___/
 *
 *=BEGIN AURALIS LICENSE
 *
 * This file is part of the IOT-UNIMORE "Auralis" project.
 *
 * Copyright (c) 2025 Gianluca Filippini. All rights reserved.
 *
 * Licensed under the MIT License (the "License");
 * you may not use this file except in compliance with the License.
 * You may obtain a copy of the License at
 *
 * https://mit-license.org/
 *
 * Unless required by applicable law or agreed to in writing, software
 * distributed under the License is distributed on an "AS IS" BASIS,
 * WITHOUT WARRANTIES OR CONDITIONS OF ANY KIND, either express or implied.
 * See the License for the specific language governing permissions and
 * limitations under the License.
 *
 *=END AURALYS LICENSE
 *
 */

/* ============================================================================= */
/* internal libraries                                                            */
/* ============================================================================= */
#include <Arduino.h>

#include <WiFi.h>
#include <WiFiManager.h>
#include <esp_wifi.h>
#include <HTTPClient.h>
#include <HTTPUpdate.h>
#include <esp_adc/adc_cali.h> // esp_adc_cal.h>
#include <esp32-hal-adc.h>

#include <ArduinoJson.h>

#include "stdint.h"
#include "esp_adc/adc_continuous.h"
#include "esp_task_wdt.h"
#include "esp32/ulp.h"
#include "soc/rtc_cntl_reg.h"
#include "driver/rtc_io.h"
#include "esp_mac.h"

#include <TimeLib.h>
/* Time.h was only a compatibility shim for TimeLib.h and is gone from the */
/* Time library since 1.6.x: TimeLib.h above is the real header.           */
// #include <Time.h>
#include <EEPROM.h>
// #include "Timezone.h"

#include <Update.h>
#include <CRC32.h>
#include <esp_partition.h>
#include <esp_ota_ops.h>
#include "FS.h"
// #include "SPIFFS.h"
#include "FFat.h"


/* ============================================================================= */
/* SOFTWARE REVISION GLOBALS&DEFINES SECTION                                     */
/* ============================================================================= */
#define BRWS_SW_PLATFORM_SIZE_MAX (16)
#define BRWS_SW_PLATFORM  "brws"
#define BRWS_SW_CODENAME_SIZE_MAX (8)
#define BRWS_SW_CODENAME  "auralysS"

/* temporary since there is no ST25 eeprom */
#define BRWS_HW_CFG_CPU_ARCH "lolin"
#define BRWS_HW_CFG_CPU_TYPE "S3mini"

/* Software Revision - BEGIN */
#define SW_VER_MJR    (0) /* NOTE: 0->255, 1byte coded */
#define SW_VER_MIN    (4) /* NOTE: 0->15,   4bit coded */
#define SW_VER_REV    (1) /* NOTE: 0->3,    2bit coded  */

/* switch define for debug/release + qa build type */
//#define DEBUG
// #define QA

/* SW VERSIONS for OTA : 0->3, 2 bit coded
 * DO NOT CHANGE THE FOLLOWING DEFINES FOR SW_VER_BUILD
 * this is a pre-defined value which is coded as follow:
 *  0 : release
 *  1 : debug
 *  2 : release-qa
 *  3 : debug-qa
 */
#ifdef DEBUG
#define LOG_MSG(...)        { Serial.print(__VA_ARGS__); }
#define LOG_MSGLN(...)      { Serial.println(__VA_ARGS__); }
#define LOG_PRINTF(...)     { Serial.printf(__VA_ARGS__); }
#define LOG_PRINTFLN(...)   { Serial.printf(__VA_ARGS__); Serial.printf("\n"); }

#ifdef QA
#define SW_VER_BUILD  (3)
#else
#define SW_VER_BUILD  (1)
#endif
#else
#define LOG_MSG(...)        /* blank */
#define LOG_MSGLN(...)      /* blank */
#define LOG_PRINTF(...)     /* blank */
#define LOG_PRINTFLN(...)   /* blank */
#ifdef QA
#define SW_VER_BUILD  (2)
#else
#define SW_VER_BUILD  (0)
#endif
#endif
/* Software Revision - END */

/* timing macros */
#define ONESEC_USECS           (1000000L)
#define ONESEC_MSECS              (1000L)
#define ONEMS_USECS               (1000L)
#define ONEHOUR_SECS              (3600L)
#define ONEMIN_SECS                 (60L)
#define ONEMS_MSECS                   (1)


/* ============================================================================= */
/* HARDWARE REVISION GLOBALS&DEFINES SECTION                                     */
/* ============================================================================= */
#include "auralys_hwconfig.h"

#define UART_MKS_TX_PIN (43)
#define UART_MKS_RX_PIN (44)
#define UART_MKS_BAUD (38400)

#define I2S_SDA_PIN (35)
#define I2S_SCL_PIN (36)

/* hostname from hw */
char device_hostname[16 + 1] = "auspkr-000000000";

/* default/empty hw configuration (read from nfctag at boot) */
HW_PCB_CONFIG_T hw_config = {
    0, /* hw_section_size */
    1, /* hw_descriptor_mjr */
    0, /* hw_descriptor_min */
    "unknown", /* hw_codename */
    "unknown", /* hw_cpu_arch */
    "unknown", /* hw_cpu_type */
    0, /* hw_pcb_ver_mjr */
    0, /* hw_pcb_ver_min */
    "01234567890123456789012345678901", /* hw_pcb_uuid4 */
    0, /* hw_unit_type */
    0, /* hw_unit_orientation */
    1, /* hw_mks_slave_addr */
    10, /* hw_mks_speed */
    1 /* hw_mks_accel */
};

/* ============================================================================= */
/* SOFTWARE LOCAL DEFINES SECTION                                                */
/* ============================================================================= */
#define USE_OLED_1106


/* ============================================================================= */
/* EEPROM GLOBALS&DEFINES SECTION                                                */
/* ============================================================================= */
#include "auralys_eeprom.h"


/* ============================================================================= */
/* EXTERNAL libaries                                                             */
/* ============================================================================= */

/* display lib */
#ifdef USE_OLED_1106
#include <Adafruit_GFX.h>
#include <Adafruit_SH110X.h>

#define SCREEN_I2C_ADDR (0x3c)
#define SCREEN_WIDTH     (128)
#define SCREEN_HEIGHT     (64)
#define OLED_RESET        (-1)

const char DISPLAY_HW_UNIT_TYPE[] = { 'N', 'L', 'R', 'F', 'S', 'T' };

Adafruit_SH1106G display = Adafruit_SH1106G(SCREEN_WIDTH, SCREEN_HEIGHT, &Wire, OLED_RESET);
#endif

/* rtc */
#include "ESP32Time.h"

/* ============================================================================= */
/* BSP GLOBALS&DEFINES SECTION                                                   */
/* ============================================================================= */
#define BSP_CPU_MHZ_MIN                                                        (10) // 10Mhz is the lowest
#define BSP_CPU_MHZ_MAX                                                       (240) // 240Mhz is the max for ESP32
#define BSP_CPU_MHZ_DEFAULT                                                   (240)

#define BSP_BTN0_00                                                             (0) // use 0 for old prototypes
#define BSP_BTN0_09                                                             (9)
#define BSP_BTN0_12                                                            (12)

#define BSP_RETRY_MAX                                                           (3)

#define BSP_DELAY_3MS                                                           (3)

/* CPU speed control */
uint32_t bspCpuMhzCurrent = BSP_CPU_MHZ_DEFAULT;
uint32_t bspCpuMhzPrevious = BSP_CPU_MHZ_DEFAULT;
uint64_t bspChipID = 0;

/* loop control */
unsigned long bspWakeUpMillis = 0;

/* display status message */
char bspDisplayCtrlMsg[64];

char bspDisplayLogMsg[2][21];
bool bspDisplayLogMsgIdx = 0;

bool bspDisplayCtrlFullscreen = false;
uint8_t bspDisplayCtrlTimeout = 0;

///* buttons control */
// volatile uint8_t bsp_btn0 = 0;
// volatile uint8_t bsp_btn0_gpio = BSP_BTN0_00;
// volatile uint8_t bsp_buz0_gpio = BSP_BUZ0_16;



/* configuration type (only DEFAULT) */
// uint8_t bspConfig = BSP_CONFIG_DEFAULT;

/* this is the eeprom variable to detect if the hw has been initialized once */
uint8_t bspInitialized = 0;
uint8_t bspActivated = 0;



/* ============================================================================= */
/* WiFi & BT GLOBALS&DEFINES SECTION                                             */
/* ============================================================================= */

/* variable used with WiFiManager added for SSID/User/Pass select */
bool volatile wifi_enabled = true;
bool volatile wifi_connected = false;


/* HTTP firmware Update */
#define HTTPUPDATE_RD_SERVER "ilbert-labs.duckdns.org"
/* note: production server same as R&D until we have a production server running */
// #define HTTPUPDATE_PRODUCTION_SERVER "www.brainworks.it"
#define HTTPUPDATE_PRODUCTION_SERVER "ilbert-labs.duckdns.org"

/* HTTP data upload */
#define HTTPSEND_RD_SERVER "ilbert-labs.duckdns.org"
/* note: production server same as R&D until we have a production server running */
// #define HTTPSEND_PRODUCTION_SERVER "www.brainworks.it"
#define HTTPSEND_PRODUCTION_SERVER "ilbert-labs.duckdns.org"

#define HTTPUPDATE_RETRY_MAX                                                    (5)
#define HTTPCONFIG_RETRY_MAX                                                    (3)
#define HTTPSEND_MAX_PAYLOAD_SIZE                                             (240)
#define HTTPSEND_MAX_PAYLOAD_ITEMS                                             (12) // 240/12
#define HTTPSEND_MIN_PAYLOAD_ITEMS                                              (6)
#define HTTPSEND_MIN_PAYLOAD_SIZE   ((EE_SECTION_EFSLOG_ITEM_SIZE - 1) * HTTPSEND_MIN_PAYLOAD_ITEMS)

/* HTTP data buffer */
const uint32_t wifiConnectTimeoutMs = 7000;
const long httpTimeoutTime2S = 5000;
unsigned long httpCurrentTime = millis();
unsigned long httpPreviousTime = 0;

RTC_DATA_ATTR bool httpUpdate_flag = false;
RTC_DATA_ATTR bool httpConfig_flag = false;

WiFiServer server(80);

WiFiClient client;
String header;

// web command defines
#define CTRL_CMD_NONE            (0)
#define CTRL_CMD_STOP            (1)
#define CTRL_CMD_POSITION_GET    (2)
#define CTRL_CMD_POSITION_SET    (3)
#define CTRL_CMD_SPEED_GET       (4)
#define CTRL_CMD_SPEED_SET       (5)
#define CTRL_CMD_ACCEL_GET       (6)
#define CTRL_CMD_ACCEL_SET       (7)
#define CTRL_CMD_RESET           (8)
#define CTRL_CMD_REBOOT          (9)
#define CTRL_CMD_MKS_RESET      (10)
#define CTRL_CMD_STATUS_GET     (11)
#define CTRL_CMD_ZERO_SET       (12)
#define CTRL_CMD_GO_ZERO        (13)
#define CTRL_CMD_MINMAX_SET     (14)
#define CTRL_CMD_UNIT_TYPE_SET  (15)


/* ============================================================================= */
/* NTP Time GLOBALS&DEFINES SECTION                                               */
/* ============================================================================= */
// #include "EasyNTPClient.h"
// WiFiUDP udp;
// EasyNTPClient ntpClient(udp, "pool.ntp.org", ((1 * 60 * 60) + (0 * 60))); // CET = GMT + 5:30

/* ============================================================================= */
/* RTC GLOBALS&DEFINES SECTION                                                   */
/* ============================================================================= */

RTC_DATA_ATTR bool rtcTimeSynced_flag = false;

ESP32Time esp32_rtc(0);

///* EU CET Eastern Time Zone (Rome) */
// TimeChangeRule myDST = { "CST", Last, Sun, Mar, 2, +120 };
// TimeChangeRule mySTD = { "CET", Last, Sun, Oct, 3, +60 };

///* UTC TimeZone is the default for "Auralys" */
// Timezone myTZ(myDST, mySTD);

// TimeChangeRule* tcr;

/* ============================================================================= */
/* RGB LED GLOBALS&DEFINES SECTION                                               */
/* ============================================================================= */
#include <Adafruit_NeoPixel.h>

uint32_t ledRgbColorCurrent = 0;
uint32_t ledRgbColorPrevious = 0;

#define LED_RGB_RED                                    ((uint32_t) (0x50000000))
#define LED_RGB_VIOLET                                 ((uint32_t) (0x50005000))
#define LED_RGB_BLUE                                   ((uint32_t) (0x00005000))
#define LED_RGB_YELLOW                                 ((uint32_t) (0x50500000))
#define LED_RGB_GREEN                                  ((uint32_t) (0x00500000))

#define LED_GRB_GREEN                                  ((uint32_t) (0x50000000))
#define LED_GRB_VIOLET                                 ((uint32_t) (0x00505000))
#define LED_GRB_BLUE                                   ((uint32_t) (0x00005000))
#define LED_GRB_YELLOW                                 ((uint32_t) (0x50500000))
#define LED_GRB_RED                                    ((uint32_t) (0x00500000))

#define LED_RGB_OFF                                                        (0x0)
#define LED_RGB_WHITE                                  ((uint32_t) (0x50505000))
#define LED_DELAY_FAST                                                     (100)
#define LED_DELAY_SLOW                                                    (1000)

/* default colors to RGB mapping, will be changed if needed by the hwconfig */
uint32_t ledRgbColorRed = LED_RGB_RED;
uint32_t ledRgbColorGreen = LED_RGB_GREEN;
uint32_t ledRgbColorBlue = LED_RGB_BLUE;
uint32_t ledRgbColorViolet = LED_RGB_VIOLET;
uint32_t ledRgbColorYellow = LED_RGB_YELLOW;
uint32_t ledRgbColorWhite = LED_RGB_WHITE;
uint32_t ledRgbColorOff = LED_RGB_OFF;


/* ***************************************************************************** */
/*  MKS MOTOR GLOBALS & DEFINES SECTION                                          */
/* ***************************************************************************** */
#define MKS_BUFFER_SIZE (32)
uint8_t txBuffer[MKS_BUFFER_SIZE]; // send data array
uint8_t rxBuffer[MKS_BUFFER_SIZE]; // Receive data array
uint8_t rxCnt = 0; // Receive data count

uint8_t mksMotorSlaveAddr = 0x01;

int32_t mksMotorMax = 0x7FFFFFFFll; //(2147483647); // +(2^31-1)
int32_t mksMotorMin = 0x80000000ll; //(-2147483648); // -(2^31)
uint16_t mksMotorSpeed = 250;
uint16_t mksMotorAccel = 3;
volatile int64_t mksMotorEncoder = 0;
bool mksMotorDirCW = true;

typedef struct mksMotorCmd_ {
    int8_t status;
    int8_t command;
    int32_t parami_01;
    int32_t parami_02;
    float paramf_01;
    float paramf_02;
}mksMotorCmd_t;

mksMotorCmd_t mksMotorCmdQueue[1] = { 0 };

#define MKS_MOTOR_STATUS_ERROR   (-1)
#define MKS_MOTOR_STATUS_IDLE     (0)
#define MKS_MOTOR_STATUS_BUSY     (1)
#define MKS_MOTOR_STATUS_EXEC     (2)



/* ============================================================================= */
/* MOTION (ACCELEROMETER) GLOBALS&DEFINES SECTION                                */
/* ============================================================================= */
#include <LIS3DSH.h>

#define LIS3DSH_ADDR (0x1D) /// Default address is 0x19, ALT is 0x18

#define  MOTION_G_FORCE                                         ((float) (9.8066))
#define  MOTION_X_AXIS                                                         (0)
#define  MOTION_Y_AXIS                                                         (1)
#define  MOTION_Z_AXIS                                                         (2)
#define  MOTION_NO_AXIS                                                        (3)
#define  MOTION_RETRY_CNT_1S                                                (1000)

#define MOTION_SENSITIVITY_2G (0.060f) // mg/LSB
#define MG_TO_MS2 (0.00980665f)

LIS3DSH sensMotion;

volatile float acc_x, acc_y, acc_z;

bool sensMotionEnabled = false;



/*
 *
 * MAIN
 *
 */


/* ***************************************************************************** */
/*  ISRs & UTILS                                                                 */
/* ***************************************************************************** */





/* ***************************************************************************** */
/*  SETUP                                                                        */
/* ***************************************************************************** */

void setup()
{
    /* loop cycle control */
    bspWakeUpMillis = millis();

    Wire.begin(I2S_SDA_PIN, I2S_SCL_PIN);
    ledRgbSetup();

#ifdef DEBUG
    /* serial port debugging will take a lot of ram */
    Serial.begin(115200);
    delay(300);
    Serial.println("\n\n\n");
    Serial.println("*********************************");
    Serial.println("AuralysSpeaker (c)2025 | UniMore ");
    Serial.println("*********************************");
    Serial.print("ver. ");
    Serial.print(SW_VER_MJR); Serial.print(".");
    Serial.print(SW_VER_MIN); Serial.print(".");
    Serial.println(SW_VER_REV);
    Serial.println("*********************************");
    Serial.printf("CHIP MAC: %012llx\r\n", ESP.getEfuseMac());
    Serial.printf("CHIP MAC: %012llx\r\n", ESP.getChipModel());
    Serial.println("*********************************");
    Serial.println("\r\n\r\n\r\n");

#if 0
    while( !Serial )
    {
        ; // wait for serial port to connect. Needed for native USB port only
    }
#endif
#endif

    eepromSetup();

    // Display splash screen
    displaySetup();
    displaySplashScreen();
    delay(2000);
    displayClear();

    // Setup platform and check for WiFi Manager connection
    bspSetup();

    displayCtrlMsg((char*) "NTP Connect..");
    displayLoop();
    ntpSetup();
    displayClearCtrlMsg();
    displayLoop();
    ledRgbSetColor(ledRgbColorOff);

    // Start the MKS serial port
    mksSetup();

    /*
     * FW UPDATE
     *
     * This will happen only at boot.
     */
    ledRgbSetColor(ledRgbColorViolet);
    displayCtrlMsg((char*) "Check FW Update..");
    displayLoop();
    if( !httpUpdate_flag )
    {
        httpUpdateInit();
        httpUpdateLoop();
    }
    displayClearCtrlMsg();
    displayLoop();
    ledRgbSetColor(ledRgbColorOff);

    /* fire up the http server */
    displayCtrlMsg((char*) "Run WebServer..");
    httpServerSetup();

    /* motion sensor */
    motionSetup();

    // bspI2CScan();

    /*
       spawn display refresh on a separate core
     */
    xTaskCreatePinnedToCore(
        &displayRefresh, // <--- <our function name
        "displayRefresh", // <--- just some string for identification
        20000, // <--- this is important - reserve enough stack otherwise strane things will happen
        NULL, // <---- you can use this if you want to pass parameter to task function, NULL otherwise
        0, // <--- 1 = normal priority, 0 = low priority, 2 = high priority
        NULL, // <--- you probabbly don't need this (from what you have described)
        0); // <--- core: 0 or 1 (Arduino by default runs its code on core 1)


    /*
       spawn motor Queue refresh on a separate core
     */
    xTaskCreatePinnedToCore(
        &motorQueueRefresh, // <--- <our function name
        "motorQueueRefresh", // <--- just some string for identification
        20000, // <--- this is important - reserve enough stack otherwise strane things will happen
        NULL, // <---- you can use this if you want to pass parameter to task function, NULL otherwise
        1, // <--- 1 = normal priority, 0 = low priority, 2 = high priority
        NULL, // <--- you probabbly don't need this (from what you have described)
        1); // <--- core: 0 or 1 (Arduino by default runs its code on core 1)

    displayCtrlMsg((char*) "Ready...");
}

/* running display loop on a separate core of S3 */
void displayRefresh(void* param)
{
    /* this is launched in a separate FreeRTOS task */
    /* needs to be encapsulated in a while(1) loop */
    while( 1 )
    {
        motionLoop();
        displayLoop();
        yield();
        delay(300);
// #ifdef DEBUG
// Serial.print("displayRefresh() running on core ");
// Serial.println(xPortGetCoreID());
// #endif
    }
}

/* running display loop on a separate core of S3 */
void motorQueueRefresh(void* param)
{
    while( 1 )
    {
        mksLoop();
        yield();
        delay(100);
    }
}

/* main loop */
void loop()
{
    bspLoop();
    ntpLoop();
    httpServerLoop();
}

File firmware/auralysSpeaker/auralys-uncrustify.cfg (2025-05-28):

# Uncrustify 0.60
# Rules for AURALYS prj 
# Version: 0.1

#################################################################################
# General options
#################################################################################


# The type of line endings
newlines                                 = auto     # auto/lf/crlf/cr

# The original size of tabs in the input
input_tab_size                           = 4        # number

# The size of tabs in the output (only used if align_with_tabs=true)
output_tab_size                          = 4        # number

# The ASCII value of the string escape char, usually 92 (\) or 94 (^). (Pawn)
string_escape_char                       = 92       # number

# Alternate string escape char for Pawn. Only works right before the quote char.
string_escape_char2                      = 0        # number

# Allow interpreting '>=' and '>>=' as part of a template in 'void f(list<list<B>>=val);'.
# If true (default), 'assert(x<0 && y>=3)' will be broken.
# Improvements to template detection may make this option obsolete.
tok_split_gte                            = false    # false/true

# Control what to do with the UTF-8 BOM (recommend 'remove')
utf8_bom                                 = ignore   # ignore/add/remove/force

# If the file contains bytes with values between 128 and 255, but is not UTF-8, then output as UTF-8
utf8_byte                                = false    # false/true

# Force the output encoding to UTF-8
utf8_force                               = false    # false/true

#################################################################################
# Indenting
#################################################################################

# The number of columns to indent per level.
# Usually 2, 3, 4, or 8.
indent_columns                           = 4        # number

# The continuation indent. If non-zero, this overrides the indent of '(' and '=' continuation indents.
# For FreeBSD, this is set to 4. Negative value is absolute and not increased for each ( level
indent_continue                          = 0        # number

# How to use tabs when indenting code
# 0=spaces only
# 1=indent with tabs to brace level, align with spaces
# 2=indent and align with tabs, using spaces when not on a tabstop
indent_with_tabs                         = 0        # number

# Comments that are not a brace level are indented with tabs on a tabstop.
# Requires indent_with_tabs=2. If false, will use spaces.
indent_cmt_with_tabs                     = false    # false/true

# Whether to indent strings broken by '\' so that they line up
indent_align_string                      = false    # false/true

# The number of spaces to indent multi-line XML strings.
# Requires indent_align_string=True
indent_xml_string                        = 0        # number

# Spaces to indent '{' from level
indent_brace                             = 0        # number

# Whether braces are indented to the body level
indent_braces                            = false    # false/true

# Disabled indenting function braces if indent_braces is true
indent_braces_no_func                    = false    # false/true

# Disabled indenting class braces if indent_braces is true
indent_braces_no_class                   = false    # false/true

# Disabled indenting struct braces if indent_braces is true
indent_braces_no_struct                  = false    # false/true

# Indent based on the size of the brace parent, i.e. 'if' => 3 spaces, 'for' => 4 spaces, etc.
indent_brace_parent                      = false    # false/true

# Whether the 'namespace' body is indented
indent_namespace                         = true    # false/true

# The number of spaces to indent a namespace block
indent_namespace_level                   = 0        # number

# If the body of the namespace is longer than this number, it won't be indented.
# Requires indent_namespace=true. Default=0 (no limit)
indent_namespace_limit                   = 0        # number

# Whether the 'extern "C"' body is indented
indent_extern                            = false    # false/true

# Whether the 'class' body is indented
indent_class                             = true    # false/true

# Whether to indent the stuff after a leading class colon
indent_class_colon                       = false    # false/true
# Whether to indent the stuff after a leading class initializer colon
indent_constr_colon                       = false    # false/true

# Virtual indent from the ':' for member initializers. Default is 2
indent_ctor_init_leading                 = 2        # number

# Additional indenting for constructor initializer list
indent_ctor_init                         = 0        # number

# False=treat 'else\nif' as 'else if' for indenting purposes
# True=indent the 'if' one level
indent_else_if                           = false    # false/true
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

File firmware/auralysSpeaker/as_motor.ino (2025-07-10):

/* ============================================================================= */
/* MKS MOTOR CONTROL                                                             */
/* ============================================================================= */

int64_t read_signed_48bit(const uint8_t* data)
{

    // mksMotorEncoder = (int64_t) (
    // ((uint64_t) value[0] << 40) |
    // ((uint64_t) value[1] << 32) |
    // ((uint64_t) value[2] << 24) |
    // ((uint64_t) value[3] << 16) |
    // ((uint64_t) value[4] << 8) |
    // ((uint64_t) value[5] << 0)
    // );

    uint64_t value = ((uint64_t) data[0] << 40) |
                     ((uint64_t) data[1] << 32) |
                     ((uint64_t) data[2] << 24) |
                     ((uint64_t) data[3] << 16) |
                     ((uint64_t) data[4] << 8) |
                     ((uint64_t) data[5] << 0);

    // Check the sign bit (bit 47) and sign-extend manually
    if( value & (1ULL << 47))
    {
        value |= 0xFFFF000000000000ULL; // Set upper 16 bits to 1
    }

    return (int64_t) value;
}

void mksSetup()
{
    Serial1.begin(UART_MKS_BAUD, SERIAL_8N1, UART_MKS_RX_PIN, UART_MKS_TX_PIN);

    /* Read setup from eeprom -> hw_config */
    mksMotorSpeed = hw_config.hw_mks_speed;
    mksMotorAccel = hw_config.hw_mks_accel;

    /* TODO: set motor mode here, depending on the role of the unit */
    /*       closed loop for speaker, serial_vfoc for poles */


}

void mksLoop()
{
    uint8_t ackStatus;

    if( MKS_MOTOR_STATUS_BUSY == mksMotorCmdQueue[0].status )
    {
        switch( mksMotorCmdQueue[0].command )
        {
            case CTRL_CMD_STOP:
                LOG_MSGLN("mksLoop: CMD_STOP");
                displayCtrlMsgTemp((char*) "STOP!", 5);
                displayCtrlLogMsg((char*) "CMD_STOP, skip");
                mksMotorCmdQueue[0].status = MKS_MOTOR_STATUS_IDLE;
                break;

            case CTRL_CMD_POSITION_GET:
                LOG_MSGLN("mksLoop: GET_POSITION");
                displayCtrlMsgTemp((char*) "GET_POSITION", 5);
                displayCtrlLogMsg((char*) "GET_POS");

                mksMotorCmdQueue[0].status = MKS_MOTOR_STATUS_EXEC;

                ackStatus = getMksEncoderValue(mksMotorSlaveAddr);

                if( ackStatus == 0 )
                {
                    mksMotorCmdQueue[0].status = MKS_MOTOR_STATUS_ERROR;
                    displayCtrlLogMsg((char*) "GET_POS: Error");
                }
                else
                {
                    const uint8_t* value = &rxBuffer[3];

                    mksMotorEncoder = read_signed_48bit(value);

                    mksMotorCmdQueue[0].status = MKS_MOTOR_STATUS_IDLE;
                }

                break;

            case CTRL_CMD_POSITION_SET:
                LOG_MSGLN("mksLoop: SET_POSITION");
                displayCtrlMsgTemp((char*) "SET_POSITION", 5);
                displayCtrlLogMsg((char*) "SET_POS");

                mksMotorCmdQueue[0].status = MKS_MOTOR_STATUS_EXEC;

                // Sanity check
                if((mksMotorCmdQueue[0].parami_01 < mksMotorMax) && (mksMotorCmdQueue[0].parami_01 > mksMotorMin))
                {
                    ackStatus = setMksMotorPosition3(mksMotorSlaveAddr, mksMotorSpeed, mksMotorAccel, mksMotorCmdQueue[0].parami_01);
                    if( ackStatus == 2 )
                    {
                        mksMotorCmdQueue[0].status = MKS_MOTOR_STATUS_IDLE;
                        displayCtrlLogMsg((char*) "SET_POS: Ok");
                    }
                    else
                    {
                        mksMotorCmdQueue[0].status = MKS_MOTOR_STATUS_ERROR;
                        displayCtrlLogMsg((char*) "SET_POS: Error");
                    }
                }
                else
                {
                    // skip command
                    mksMotorCmdQueue[0].status = MKS_MOTOR_STATUS_IDLE;
                    displayCtrlLogMsg((char*) "SET_POS: Skipped");
                }

                break;

            case CTRL_CMD_SPEED_GET:
                LOG_MSGLN("mksLoop: GET_SPEED, not supported yet");
                displayCtrlLogMsg((char*) "CMD_SPEED_GET, skip");
                mksMotorCmdQueue[0].status = MKS_MOTOR_STATUS_IDLE;
                break;

            case CTRL_CMD_ACCEL_SET:
                LOG_MSGLN("mksLoop: SET_ACCEL, not supported yet");
                displayCtrlLogMsg((char*) "CMD_ACCEL_SET, skip");
                mksMotorCmdQueue[0].status = MKS_MOTOR_STATUS_IDLE;
                break;

            case CTRL_CMD_ACCEL_GET:
                LOG_MSGLN("mksLoop: GET_ACCEL, not supported yet");
                displayCtrlLogMsg((char*) "CMD_ACCEL_GET, skip");
                mksMotorCmdQueue[0].status = MKS_MOTOR_STATUS_IDLE;
                break;

            case CTRL_CMD_SPEED_SET:
                LOG_MSGLN("mksLoop: SET_SPEED, not supported yet");
                displayCtrlLogMsg((char*) "CMD_SPEED_SET, skip");
                mksMotorCmdQueue[0].status = MKS_MOTOR_STATUS_IDLE;
                break;

            case CTRL_CMD_MKS_RESET:
                LOG_MSGLN("mksLoop: MKS_RESET, not supported yet");
                displayCtrlLogMsg((char*) "CMD_MKS_RESET, skip");
                /* add here other motor control operations, like stop */
                mksMotorCmdQueue[0].status = MKS_MOTOR_STATUS_IDLE;
                break;

            case CTRL_CMD_STATUS_GET:
                LOG_MSGLN("mksLoop: CTRL_CMD_STATUS_GET, not supported yet");
                displayCtrlLogMsg((char*) "CMD_STATUS_GET, skip");
                mksMotorCmdQueue[0].status = MKS_MOTOR_STATUS_IDLE;
                break;

            case CTRL_CMD_ZERO_SET:
                LOG_MSGLN("mksLoop: CTRL_CMD_ZERO_SET");
                displayCtrlLogMsg((char*) "CMD_ZERO_SET");

                mksMotorCmdQueue[0].status = MKS_MOTOR_STATUS_EXEC;
                ackStatus = mksSetAxisZero(mksMotorSlaveAddr);
                if( ackStatus == 1 )
                {
                    mksMotorCmdQueue[0].status = MKS_MOTOR_STATUS_IDLE;
                    displayCtrlLogMsg((char*) "CMD_ZERO_SET, Ok");

                }
                else
                {
                    mksMotorCmdQueue[0].status = MKS_MOTOR_STATUS_ERROR;
                    displayCtrlLogMsg((char*) "CMD_ZERO_SET, Error");

                }
                break;

            case CTRL_CMD_GO_ZERO:
                LOG_MSGLN("mksLoop: CTRL_CMD_GO_ZERO, not supported yet");
                displayCtrlLogMsg((char*) "CMD_GO_ZERO, skip");
                mksMotorCmdQueue[0].status = MKS_MOTOR_STATUS_IDLE;
                break;

            default:
                LOG_MSGLN("mksLoop: unknown MKS command, skipped");
                displayCtrlLogMsg((char*) "CMD Unknown, skip");
                mksMotorCmdQueue[0].status = MKS_MOTOR_STATUS_IDLE;
        }

    }
}
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

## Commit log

2025-05-28 wip on speaker
    [auralys-uncrustify.cfg]
2025-05-30 fix http server delay
    [as_httpserver.ino, as_motor.ino, auralysSpeaker.ino]
2025-05-30 adding accelerometer LIS3DSH
2025-06-09 re-enable accelerometer
2025-06-10 adding rotating table motor control
2025-06-10 adding rotating table encoder code
2025-06-12 fix motor position int64_t sign extension
    [as_motor.ino, auralysSpeaker.ino]
2025-06-15 adding controller board schematic
    [auralys_mks_controller_ESP32S3_BOM.csv]
2025-06-18 fix ess_map script and add quick script for fully automated hrtf capture
    [hrtf_coordinates.xls]
2025-06-30 fix uncrustify rules with last version of uncrustify
    [auralys-uncrustify.cfg]
2025-06-30 fix speed and position polling on rotating table motor control
2025-07-02 disable wifi standby for auralysSpeaker arduino prj
2025-07-10 auralysSpeaker: fix max/min range for motor position control
    [as_motor.ino, auralysSpeaker.ino]
2025-07-11 add also control for rotating table, now using the same control fw on all step-motors
2025-07-22 fix cmf_get_position, remove leftover print
2025-07-27 refine positions based on speaker zero_position of 700,0,1300 at the speaker cone center reference
    [hrtf_coordinates.xls]
2025-07-27 position values with new calibration
2025-07-31 removing the old code for rotating table since auralysSpeaker does it all
    [auralys-uncrustify.cfg]
2025-08-16 w.i.p on record_audio sample accuracy
2025-08-17 bugfix: use the correct order of track number when muxing Auralys WAV->MKV files
2025-09-15 BIRI: actually the 3Dti tool requires the BRIR to remove the samples before the direct path and also zero-out the direct path, enabling zero_delay option
2025-10-12 adding hw documents
    [center_shaft_bearing_support.stl, center_shaft_flange_extension.stl, spurgear_90cm_element_x4.stl]
2025-10-20 speaker details
    [gimbal_curve.stl, gimbal_plate.stl, gimbal_side.stl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]
2025-10-20 adding stepper motor for rotating table
    [Ear_left.STL, Ear_right.stl, Head_back.STL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]
2025-10-20 add motor control info
2025-10-20 adding details on standing poles
    [MKS_ctrl_star_mount.stl, auralys_standing_pole.stl, mks_9cm-II_spool.stl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]
2025-10-20 adding mic schematics
2026-08-29 update auralysSpeaker arduino code and auto-build script
2026-08-29 IMPORTANT: improve positioning while avoiding flooding calls to the devices, change audio recording asyncio calls
2026-08-29 keeping track of the default geometry of our rig
2026-09-13 add faital spacer
    [Faital-4FE32.stl]
2026-09-13 update flange
    [mks_wilpkr_flange_v2.stl]
2026-09-18 update hardware resources
    [MKS_RTable_base.stl, MKS_RTable_gearbox_plate.stl]
